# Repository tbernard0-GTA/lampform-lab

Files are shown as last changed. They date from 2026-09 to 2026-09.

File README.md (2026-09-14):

# LampForm Lab v0.9 — Entender, escolher, comparar, imprimir

[Story](https://lampform-lab.oieszc.chatgpt.site/) · [Design](https://lampform-lab.oieszc.chatgpt.site/design/) · [Test](https://lampform-lab.oieszc.chatgpt.site/test/) · [Advanced](https://lampform-lab.oieszc.chatgpt.site/advanced/)

Cinco capítulos apresentam a pesquisa. Design guia uma decisão por tela: peça, pergunta, hipótese, comparação visual e interpretação. Os resultados mostram separadamente melhora, piora e custo de material, sem um score que esconda os trade-offs. Advanced reúne os 48 designs e os dados de engenharia.

As peças e arquivos finais agora se chamam **Peça 1** e **Peça 2**. Os pacotes incluem `peca-1-controle.stl`, `peca-1-largura.stl`, `peca-1-altura.stl`, `peca-1-combinada.stl` e `molde-peca-1.stl`, com equivalentes para Peça 2. Os nomes técnicos internos são preservados para manter a rastreabilidade.

Esta versão muda somente a experiência. Solver, catálogo, métricas e STLs da v0.8 permanecem idênticos, verificados por hash. Os arquivos renomeados são cópias exatas. [Decisões de experiência](docs/V09_EXPERIENCE.md).

`npm run build` recompila a interface; `npm test` verifica o conjunto. As imagens e pacotes já estão incluídos. Para recriar apenas esses materiais, use Python com as dependências do projeto e execute `scripts/render-test-thumbnails.py`, `scripts/build-comparison-visuals.py` e `scripts/package-public-tests.py`, nessa ordem. Nenhum deles executa o solver.

## Referência: v0.8 — Parametric Lattice Design Lab

[A história](https://lampform-lab.oieszc.chatgpt.site) · [Design Lab](https://lampform-lab.oieszc.chatgpt.site/design/) · [STLs e mapas V2](https://lampform-lab.oieszc.chatgpt.site/downloads/LAMPFORM_PARAMETRIC_TEST_V2.zip)

A página inicial conta a pesquisa em sete capítulos. O laboratório separa os controles avançados e oferece 48 configurações calculadas: Honeycomb, Triangle e Diamond, comparação por volume equivalente e um experimento de largura versus altura para as duas peças.

Cada seleção corresponde a uma geometria, solver e STL reais. Os controles ajustam explicitamente a seleção ao catálogo disponível; não existe interpolação de métricas ou execução do solver no navegador. A adaptação local está disponível em Honeycomb. Triangle e Diamond têm estados uniformes e de volume equivalente.

O pacote V2 tem A uniforme, B largura variável, C altura variável e D ambas, por peça. Alturas em passos de 0,1 mm; B/C/D usam aproximadamente +10% de volume da malha. São hipóteses para ensaio, sem comprovação física. A altura variável não melhora todos os resultados.

Regenerar: `npm run analysis:parametric` com o ambiente Python ativado; depois `npm run build` e `npm test`. O script BUILD inclui todas as análises. [Método v0.8](docs/V08_IMPLEMENTATION_NOTES.md) · [Resultados completos](docs/V08_CALCULATED_CATALOG.md).

## Referência preservada: v0.6 — Physical Validation Loop

[Aplicação pública](https://lampform-lab.oieszc.chatgpt.site) · [Story Mode](https://lampform-lab.oieszc.chatgpt.site/story.html?scene=01) · [Método e resultados v0.6](docs/LAMPFORM_V06_PHYSICAL_VALIDATION.md) · [Storyboard](docs/VIDEO_STORYBOARD.md)

Uma bancada para prever, fabricar, medir e comparar uma luminária impressa plana e termoformada. Não existem medições físicas ou calibração do polímero nesta versão.

## Novidades v0.6

Geometry → Deformation → Mechanisms → Design → Compare → Experiment → Calibration → Print. Inspecione λ1, λ2, J, anisotropia e direções por célula. Use Change only e Zoom da alteração para examinar os novos testes. HAB-2 e Sub-Merged têm escolhas independentes e podem ser baixadas juntas num ZIP.

Print oferece A/B/C/D do Sub-Merged, com STL reais, plano de 20 células por peça, template e procedimento. B/C/D investigam mecanismos; não melhoram o P95 no modelo atual. Os originais fornecidos e os reparados têm arquivos separados.

Experiment aceita CSV/JSON e entrada manual. Os dados ficam na memória deste navegador; exporte antes de fechar ou recarregar. Valores ausentes permanecem ausentes. A calibração usa Original e uma amostra Candidate separada da mesma peça.

Story Mode tem 12 cenas. Setas e Space navegam; Esc volta à bancada. Abra `story.html?scene=06` ou `story.html?scene=06&mode=capture` para gravação limpa em 16:9. Capture frame exporta a cena atual; `npm run capture-story` gera as 12 imagens offline em `docs/video_frames/`, com os mesmos dados e composição própria.

O site compilado e os resultados já estão incluídos. `npm start` ou `PLAY-LAMPFORM-LAB.cmd` abre localmente. Depois de instalar as dependências abaixo, a geração completa usa:

```powershell
.\.venv\Scripts\python.exe analysis/build_design_space.py
.\.venv\Scripts\python.exe analysis/build_physical.py
npm run build
npm test
npm run capture-story
```

`BUILD-LAMPFORM-LAB.cmd` inclui as duas análises. Com o ambiente Python ativado, `npm run analysis:physical` regenera a v0.6. Depois de obter medidas reais, exporte um trabalho na aba Calibration e execute `python analysis/calibrate_physical.py calibration_job.json`. Importe o relatório selecionando os mesmos datasets. Ele não substitui silenciosamente as previsões base.

O catálogo v0.6 usa `dist/data/physical/results.json`. A bancada anterior está preservada em [workbench-v05.html](https://lampform-lab.oieszc.chatgpt.site/workbench-v05.html). O método, limites e resultados negativos estão documentados no relatório v0.6.

## Referência preservada: Engineering Workbench v0.5

[Aplicação pública](https://lampform-lab.oieszc.chatgpt.site) · [Relatório de engenharia](docs/LAMPFORM_V05_ENGINEERING_REPORT.md)

Uma bancada visual para investigar uma luminária impressa plana e termoformada. Compare Original e candidatos reais, localize concentração de demanda, veja mudanças geométricas, diferenças e alimentação XY, e baixe o STL exato.

## Uso

Abra o site e selecione HAB-2 ou Sub-Merged, família e intensidade. Os dois viewers compartilham câmera e escala de cores. O mapa plano permite inspecionar células, sobrepor geometrias, mostrar apenas alterações, examinar delta e vetores XY. Danger zones, matriz ordenável e gráficos separam risco de custo de fabricação. Story / About conta o contexto.

Os resultados são calculados offline. O site não executa Python, não recebe uploads e não oferece edição pública. O repositório é público; modificações no repositório principal dependem do proprietário. A visibilidade pública permite leitura e forks conforme as regras do GitHub; não concede acesso de escrita.

## Gerar novamente

Requisitos: Python 3.13+ e Node.js 22+. Dependências científicas fixadas em requirements-analysis.txt.

No Windows: execute BUILD-LAMPFORM-LAB.cmd. Depois use PLAY-LAMPFORM-LAB.cmd para abrir localmente.

```powershell
python -m venv .venv
.\.venv\Scripts\python.exe -m pip install -r requirements-analysis.txt
npm ci
.\.venv\Scripts\python.exe analysis/build_design_space.py
npm run build
npm test
npm start
```

Com o ambiente Python ativado, o comando principal é `python analysis/build_design_space.py`. A pipeline anterior permanece disponível em `python analysis/run_design_sweep.py` e gera o catálogo v0.4 separado.

O modo opcional `--reuse-solutions` reaproveita soluções somente se coordenadas, arestas, larguras, comprimentos, ancoragens, parent IDs, parâmetros do solver e hash do STL coincidirem. O modo padrão recalcula tudo.

## Modelo e gates

Dez designs iniciais: Original e três intensidades de Reserve, Boundary e Hybrid. Se nenhum par passar, até três perturbações adicionais de Reserve são testadas. Cada tentativa fica em generated/sweep/. Sem ML e sem métricas interpoladas.

Risco: 30% P95 + 25% P99 + 25% máximo + 20% fração crítica, normalizados ao Original. Material e área aberta ficam separados. Print gate: P95 menor, menos ligamentos acima de 30%, pico no máximo +5 pontos percentuais, solução convergida e geometria válida. A recomendação exige aprovação das DUAS peças. Nenhum vencedor é inventado se a busca terminar sem aprovação.

## Arquivos

- legacy/: material original preservado, incluindo os quatro STL e os scripts v0.1/v0.2.
- analysis/: geometria, rede estrutural, solver, geração, gates, exportação e relatórios.
- config/manufacturing.yaml: defaults de fabricação (JSON compatível com YAML 1.2).
- generated/baseline_reproduction.json: comparação da reprodução dos scripts originais.
- generated/sweep/: resultados, parâmetros, redes e CSV de todas as tentativas.
- dist/data/results.json: catálogo completo v0.5.
- dist/downloads/: STL e ZIP reais, métricas, parâmetros e instruções.
- web/: fonte do app estático; dist/: versão compilada publicada.

## Limites

É um modelo de demanda geométrica/estrutural relativa, não FEA termomecânico calibrado. Não prevê temperatura, E(T), viscoelasticidade, atrito, anisotropia ou ruptura real. A vista formada é a rede analítica nas etapas calculadas; o STL exato é mostrado plano.

Os STL originais das lâmpadas têm faces duplicadas e não são watertight; são preservados sem reparos. Os candidatos são novos sólidos fechados e mantêm o aro original. Mold e Push nunca são alterados. Os checks de largura cobrem caminhos estruturais e a sonda de abertura cobre células principais; cantos e vãos periféricos devem ser revistos no slicer.

Consulte o relatório para resultados, rejeições, alcance da validação e recomendação física (ou ausência dela).

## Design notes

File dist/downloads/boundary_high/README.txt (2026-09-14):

LampForm Lab v0.5 / Boundary High
Both-part print gate: False
Boundary High: abertura equivalente média 6.65 mm; material projetado -2.4%; geometria plana alterada 69.1%. P95 36.0 → 47.3%; P99 45.3 → 74.0%; pico 64.3 → 87.8%; críticos 45 → 60. Transição com núcleo escalado a 96.0%, conectores de 0.95 mm e amplitude máxima 0.65 mm. Gates: REJECTED.
Boundary High: abertura equivalente média 6.65 mm; material projetado -2.4%; geometria plana alterada 69.1%. P95 55.5 → 108.8%; P99 70.1 → 132.2%; pico 83.9 → 158.9%; críticos 98 → 104. Transição com núcleo escalado a 96.0%, conectores de 0.95 mm e amplitude máxima 0.65 mm. Gates: REJECTED.
Units mm. Flat lattice 1 mm, original rim 4 mm. Inspect layers in your slicer. Relative geometric model, not calibrated polymer strain. Mold and Push unchanged. Original source meshes have duplicated faces and are not watertight.

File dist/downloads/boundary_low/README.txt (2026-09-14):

LampForm Lab v0.5 / Boundary Low
Both-part print gate: False
Boundary Low: abertura equivalente média 6.85 mm; material projetado -0.0%; geometria plana alterada 27.0%. P95 36.0 → 36.1%; P99 45.3 → 55.5%; pico 64.3 → 62.4%; críticos 45 → 55. Transição com núcleo escalado a 99.0%, conectores de 1.20 mm e amplitude máxima 0.15 mm. Gates: REJECTED.
Boundary Low: abertura equivalente média 6.85 mm; material projetado -0.0%; geometria plana alterada 27.0%. P95 55.5 → 112.2%; P99 70.1 → 161.3%; pico 83.9 → 182.3%; críticos 98 → 106. Transição com núcleo escalado a 99.0%, conectores de 1.20 mm e amplitude máxima 0.15 mm. Gates: REJECTED.
Units mm. Flat lattice 1 mm, original rim 4 mm. Inspect layers in your slicer. Relative geometric model, not calibrated polymer strain. Mold and Push unchanged. Original source meshes have duplicated faces and are not watertight.

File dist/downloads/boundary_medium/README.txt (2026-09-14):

LampForm Lab v0.5 / Boundary Medium
Both-part print gate: False
Boundary Medium: abertura equivalente média 6.79 mm; material projetado -0.9%; geometria plana alterada 45.9%. P95 36.0 → 40.0%; P99 45.3 → 58.1%; pico 64.3 → 75.2%; críticos 45 → 43. Transição com núcleo escalado a 98.0%, conectores de 1.05 mm e amplitude máxima 0.35 mm. Gates: REJECTED.
Boundary Medium: abertura equivalente média 6.79 mm; material projetado -0.9%; geometria plana alterada 45.9%. P95 55.5 → 99.5%; P99 70.1 → 131.1%; pico 83.9 → 162.0%; críticos 98 → 110. Transição com núcleo escalado a 98.0%, conectores de 1.05 mm e amplitude máxima 0.35 mm. Gates: REJECTED.
Units mm. Flat lattice 1 mm, original rim 4 mm. Inspect layers in your slicer. Relative geometric model, not calibrated polymer strain. Mold and Push unchanged. Original source meshes have duplicated faces and are not watertight.

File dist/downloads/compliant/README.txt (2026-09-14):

LampForm Lab v0.4 / compliant
Units: mm. Flat pieces; lattice 1 mm, rim 4 mm.
HAB-2 -> Mold; Sub-Merged -> Push. Tools are unchanged.
Open both STL in a slicer and inspect layers before printing.
Relative geometric/structural demand, NOT calibrated polymer strain.
Parameters, convergence and mesh checks are in the accompanying JSON files.
Candidate geometry reloaded and checked closed, single body, with no duplicate or degenerate faces.

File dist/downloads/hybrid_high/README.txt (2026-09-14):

LampForm Lab v0.5 / Hybrid High
Both-part print gate: False
Hybrid High: abertura equivalente média 6.20 mm; material projetado +18.3%; geometria plana alterada 65.3%. P95 36.0 → 44.0%; P99 45.3 → 86.5%; pico 64.3 → 116.1%; críticos 45 → 55. Transição com núcleo escalado a 96.0%, conectores de 0.95 mm e amplitude máxima 0.65 mm. Gates: REJECTED.
Hybrid High: abertura equivalente média 6.32 mm; material projetado +13.3%; geometria plana alterada 65.6%. P95 55.5 → 75.7%; P99 70.1 → 130.9%; pico 83.9 → 179.3%; críticos 98 → 92. Transição com núcleo escalado a 96.0%, conectores de 0.95 mm e amplitude máxima 0.65 mm. Gates: REJECTED.
Units mm. Flat lattice 1 mm, original rim 4 mm. Inspect layers in your slicer. Relative geometric model, not calibrated polymer strain. Mold and Push unchanged. Original source meshes have duplicated faces and are not watertight.

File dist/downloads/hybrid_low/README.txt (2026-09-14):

LampForm Lab v0.5 / Hybrid Low
Both-part print gate: False
Hybrid Low: abertura equivalente média 6.76 mm; material projetado +4.5%; geometria plana alterada 27.0%. P95 36.0 → 37.9%; P99 45.3 → 57.9%; pico 64.3 → 68.4%; críticos 45 → 42. Transição com núcleo escalado a 99.0%, conectores de 1.20 mm e amplitude máxima 0.15 mm. Gates: REJECTED.
Hybrid Low: abertura equivalente média 6.79 mm; material projetado +3.4%; geometria plana alterada 26.7%. P95 55.5 → 114.0%; P99 70.1 → 172.0%; pico 83.9 → 188.3%; críticos 98 → 103. Transição com núcleo escalado a 99.0%, conectores de 1.20 mm e amplitude máxima 0.15 mm. Gates: REJECTED.
Units mm. Flat lattice 1 mm, original rim 4 mm. Inspect layers in your slicer. Relative geometric model, not calibrated polymer strain. Mold and Push unchanged. Original source meshes have duplicated faces and are not watertight.

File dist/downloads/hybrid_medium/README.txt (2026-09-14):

LampForm Lab v0.5 / Hybrid Medium
Both-part print gate: False
Hybrid Medium: abertura equivalente média 6.51 mm; material projetado +12.3%; geometria plana alterada 44.7%. P95 36.0 → 39.8%; P99 45.3 → 71.3%; pico 64.3 → 77.2%; críticos 45 → 40. Transição com núcleo escalado a 98.0%, conectores de 1.05 mm e amplitude máxima 0.35 mm. Gates: REJECTED.
Hybrid Medium: abertura equivalente média 6.59 mm; material projetado +9.0%; geometria plana alterada 44.1%. P95 55.5 → 85.5%; P99 70.1 → 136.2%; pico 83.9 → 187.6%; críticos 98 → 108. Transição com núcleo escalado a 98.0%, conectores de 1.05 mm e amplitude máxima 0.35 mm. Gates: REJECTED.
Units mm. Flat lattice 1 mm, original rim 4 mm. Inspect layers in your slicer. Relative geometric model, not calibrated polymer strain. Mold and Push unchanged. Original source meshes have duplicated faces and are not watertight.

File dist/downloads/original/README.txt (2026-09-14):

LampForm Lab v0.5 / Original
Both-part print gate: False
Original: abertura equivalente média 6.93 mm; material projetado +0.0%; geometria plana alterada 0.0%. P95 36.0 → 36.0%; P99 45.3 → 45.3%; pico 64.3 → 64.3%; críticos 45 → 45. Gates: BASE.
Original: abertura equivalente média 6.93 mm; material projetado +0.0%; geometria plana alterada 0.0%. P95 55.5 → 55.5%; P99 70.1 → 70.1%; pico 83.9 → 83.9%; críticos 98 → 98. Gates: BASE.
Units mm. Flat lattice 1 mm, original rim 4 mm. Inspect layers in your slicer. Relative geometric model, not calibrated polymer strain. Mold and Push unchanged. Original source meshes have duplicated faces and are not watertight.

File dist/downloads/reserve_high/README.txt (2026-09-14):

LampForm Lab v0.5 / Reserve High
Both-part print gate: False
Reserve High: abertura equivalente média 6.47 mm; material projetado +20.7%; geometria plana alterada 24.1%. P95 36.0 → 29.6%; P99 45.3 → 34.9%; pico 64.3 → 37.0%; críticos 45 → 10. Gates: PASS.
Reserve High: abertura equivalente média 6.61 mm; material projetado +14.5%; geometria plana alterada 18.3%. P95 55.5 → 51.4%; P99 70.1 → 97.6%; pico 83.9 → 107.8%; críticos 98 → 88. Gates: TRADE-OFF.
Units mm. Flat lattice 1 mm, original rim 4 mm. Inspect layers in your slicer. Relative geometric model, not calibrated polymer strain. Mold and Push unchanged. Original source meshes have duplicated faces and are not watertight.

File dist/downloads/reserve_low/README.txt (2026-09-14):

LampForm Lab v0.5 / Reserve Low
Both-part print gate: False
Reserve Low: abertura equivalente média 6.83 mm; material projetado +4.5%; geometria plana alterada 7.0%. P95 36.0 → 35.4%; P99 45.3 → 46.7%; pico 64.3 → 69.0%; críticos 45 → 43. Gates: PASS.
Reserve Low: abertura equivalente média 6.86 mm; material projetado +3.2%; geometria plana alterada 5.3%. P95 55.5 → 53.3%; P99 70.1 → 72.8%; pico 83.9 → 88.1%; críticos 98 → 98. Gates: TRADE-OFF.
Units mm. Flat lattice 1 mm, original rim 4 mm. Inspect layers in your slicer. Relative geometric model, not calibrated polymer strain. Mold and Push unchanged. Original source meshes have duplicated faces and are not watertight.

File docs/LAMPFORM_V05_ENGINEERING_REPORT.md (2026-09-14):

# LampForm Lab v0.5 — Engineering report

Generated: 2026-09-14T16:59:59.122447+00:00

## Baseline problem

The supplied v0.1 and v0.2 solvers were reproduced without editing legacy; deviations below 0.02 percentage point are recorded in `generated/baseline_reproduction.json`. This DOE recomputes its own baseline with exactly the candidate solver. It merges nominally coincident corners at 0.03 mm and includes 20 actual rim connectors: 246 parent ligaments per part. Reported demand is the maximum positive segment strain per physical parent, so subdividing a connector does not dilute percentiles. The original STL are copied byte-for-byte; both contain 503 duplicated faces and are not watertight.

## Design space and mechanisms

Ten initial designs: Original and Low/Medium/High Reserve, Boundary and Hybrid. Reserve reduces cell openings by up to 2/6/10%, spatially smoothed over 12 mm. Boundary contracts the core to 99/98/96% and adds actual S connectors, width 1.20/1.05/0.95 mm and maximum amplitude 0.15/0.35/0.65 mm. Hybrid combines these levels. Nominal boundary-band parameters 0.4/0.8/1.6 mm are converted to isotropic scale using a 40 mm reference; actual gap varies along the perimeter. Boundary changes pitch and connectors together: their individual effects are not isolated. If no pair passes, a bounded second pass tests reserve strengths 0.005, 0.01, 0.035, stopping at the first pass or 13 designs total. Every attempted result is stored in `generated/sweep/` and exposed in the explorer.

## Danger zones and risk

LOW <10%; MODERATE 10–<20%; HIGH 20–30%; CRITICAL >30%. These are relative demand classes, not polymer failure limits. Risk Index = 0.30(P95/P95₀) + 0.25(P99/P99₀) + 0.25(max/max₀) + 0.20(critical fraction/critical fraction₀). Material and open area are excluded. If baseline has zero critical ligaments the denominator floor is one edge. Print gate requires lower P95, fewer >30% ligaments, max ≤ baseline +5 percentage points, valid geometry, closed single body, minimum structural path width and aperture probe. A pair is recommended only when BOTH parts pass. Gates are selection heuristics, not a safety certification.

## Results

| Design | Part | P95 | P99 | Max | Critical | Risk | Material Δ | Gate |
|---|---|---:|---:|---:|---:|---:|---:|---|
| Original | hab2 | 35.98% | 45.29% | 64.33% | 45 | 1.000 | +0.0% | BASE |
| Original | submerged | 55.47% | 70.12% | 83.86% | 98 | 1.000 | +0.0% | BASE |
| Reserve Low | hab2 | 35.35% | 46.73% | 69.03% | 43 | 1.012 | +4.5% | PASS |
| Reserve Low | submerged | 53.26% | 72.81% | 88.13% | 98 | 1.010 | +3.2% | TRADE-OFF |
| Reserve Medium | hab2 | 34.32% | 48.83% | 80.79% | 44 | 1.065 | +12.7% | TRADE-OFF |
| Reserve Medium | submerged | 50.92% | 79.41% | 87.02% | 93 | 1.008 | +8.9% | PASS |
| Reserve High | hab2 | 29.61% | 34.93% | 36.98% | 10 | 0.628 | +20.7% | PASS |
| Reserve High | submerged | 51.44% | 97.61% | 107.80% | 88 | 1.127 | +14.5% | TRADE-OFF |
| Boundary Low | hab2 | 36.09% | 55.50% | 62.38% | 55 | 1.094 | -0.0% | REJECTED |
| Boundary Low | submerged | 112.17% | 161.33% | 182.30% | 106 | 1.942 | -0.0% | REJECTED |
| Boundary Medium | hab2 | 39.97% | 58.10% | 75.23% | 43 | 1.137 | -0.9% | REJECTED |
| Boundary Medium | submerged | 99.51% | 131.07% | 161.99% | 110 | 1.713 | -0.9% | REJECTED |
| Boundary High | hab2 | 47.33% | 73.95% | 87.81% | 60 | 1.411 | -2.4% | REJECTED |
| Boundary High | submerged | 108.82% | 132.17% | 158.89% | 104 | 1.746 | -2.4% | REJECTED |
| Hybrid Low | hab2 | 37.85% | 57.93% | 68.41% | 42 | 1.088 | +4.5% | REJECTED |
| Hybrid Low | submerged | 114.04% | 171.98% | 188.27% | 103 | 2.001 | +3.4% | REJECTED |
| Hybrid Medium | hab2 | 39.81% | 71.34% | 77.18% | 40 | 1.203 | +12.3% | REJECTED |
| Hybrid Medium | submerged | 85.49% | 136.22% | 187.57% | 108 | 1.728 | +9.0% | REJECTED |
| Hybrid High | hab2 | 44.00% | 86.47% | 116.06% | 55 | 1.540 | +18.3% | REJECTED |
| Hybrid High | submerged | 75.66% | 130.86% | 179.33% | 92 | 1.598 | +13.3% | REJECTED |
| Reserve Search 1 | hab2 | 32.65% | 37.77% | 63.03% | 34 | 0.877 | +1.3% | PASS |
| Reserve Search 1 | submerged | 54.49% | 69.90% | 84.00% | 100 | 0.998 | +1.0% | TRADE-OFF |
| Reserve Search 2 | hab2 | 35.55% | 46.54% | 66.90% | 43 | 1.004 | +2.4% | PASS |
| Reserve Search 2 | submerged | 53.91% | 70.35% | 85.52% | 98 | 0.997 | +1.7% | TRADE-OFF |
| Reserve Search 3 | hab2 | 29.72% | 32.24% | 35.06% | 10 | 0.606 | +7.6% | PASS |
| Reserve Search 3 | submerged | 50.59% | 71.25% | 84.63% | 97 | 0.978 | +5.3% | PASS |

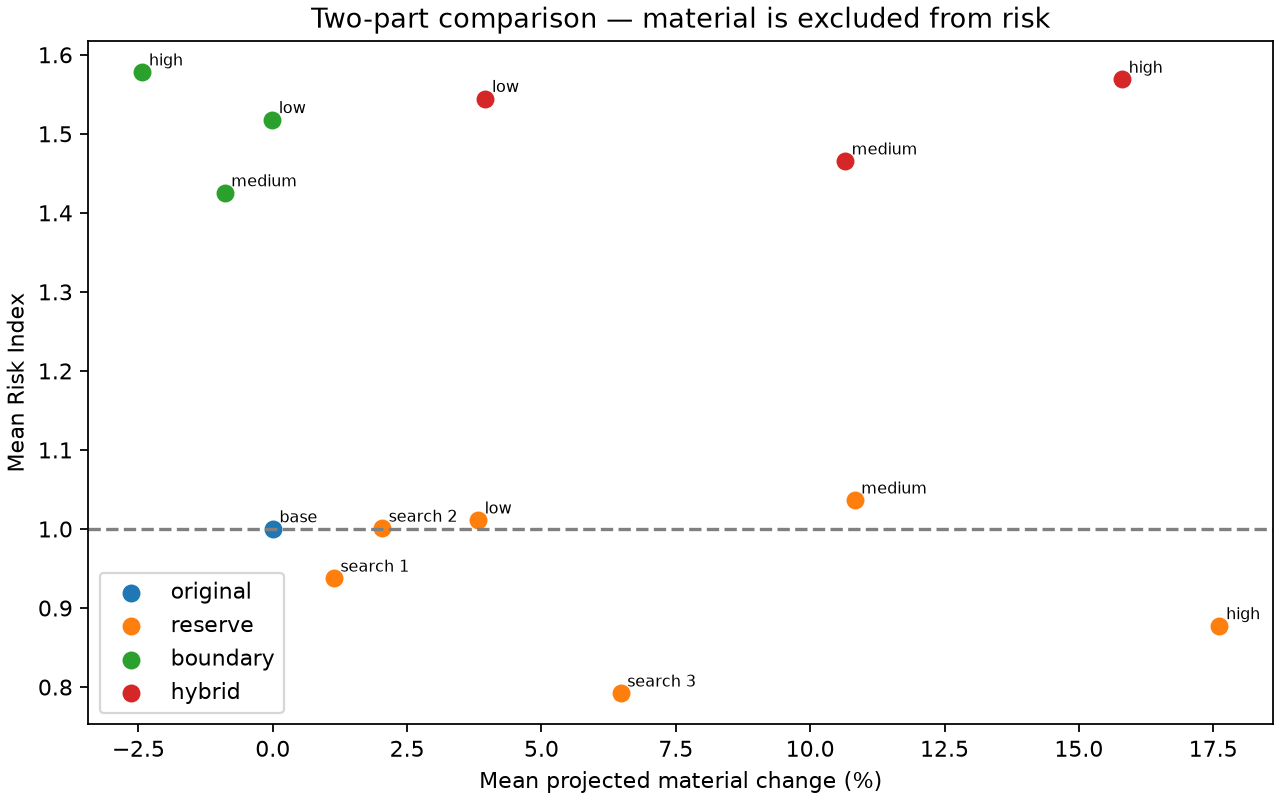
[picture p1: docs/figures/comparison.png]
Risk versus material


## Sensitivity: material, boundary or combination?

- Reserve: two-part Risk Index range 0.878–1.036; 0 pairs passed.
- Boundary: two-part Risk Index range 1.425–1.578; 0 pairs passed.
- Hybrid: two-part Risk Index range 1.465–1.569; 0 pairs passed.

The smallest observed risk in this tested space belongs to reserve. This is a comparison of tested perturbations, not a causal attribution or proof of global optimality. The boundary family alters both pitch and connector shape. A matched-pitch follow-up and physical measurements are needed to isolate rim feed from material amount.

## Rejected candidates

- Reserve Low: submerged: critical_edges
- Reserve Medium: hab2: maximum
- Reserve High: submerged: maximum
- Boundary Low: hab2: p95, hab2: critical_edges, submerged: p95, submerged: critical_edges, submerged: maximum
- Boundary Medium: hab2: p95, hab2: maximum, submerged: p95, submerged: critical_edges, submerged: maximum
- Boundary High: hab2: p95, hab2: critical_edges, hab2: maximum, submerged: p95, submerged: critical_edges, submerged: maximum
- Hybrid Low: hab2: p95, submerged: p95, submerged: critical_edges, submerged: maximum
- Hybrid Medium: hab2: p95, hab2: maximum, hab2: solver_converged, submerged: p95, submerged: critical_edges, submerged: maximum
- Hybrid High: hab2: p95, hab2: critical_edges, hab2: maximum, hab2: solver_converged, submerged: p95, submerged: maximum
- Reserve Search 1: submerged: critical_edges
- Reserve Search 2: submerged: critical_edges

## Geometry changes and map correspondence

Parent IDs preserve lattice topology and the same attachment sites across designs; cell IDs preserve original centers, with scaled positions in boundary families. Delta = candidate parent demand − original parent demand, in percentage points. The maps show exact flat footprints plus the corresponding analytical paths. Equivalent hole size = sqrt(2×hole area/sqrt(3)); this is across-flats only for a regular hexagon. Curved candidates use area-equivalent size. Geometry changed % is symmetric-difference area divided by union area, excluding the retained rim. Hole outlines are re-extracted after all unions/cuts. The formed view shows the analytical network, never a fabricated deformed solid. Its five steps are actual continuation solutions.

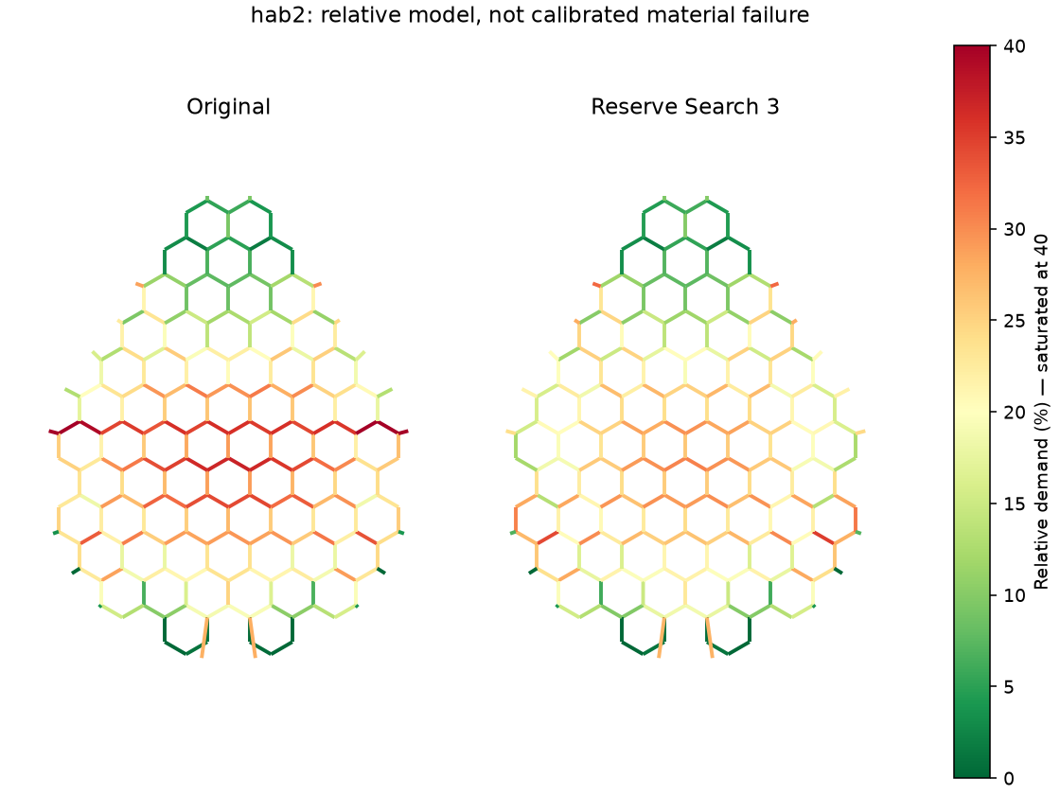
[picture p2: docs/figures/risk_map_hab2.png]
HAB-2 risk

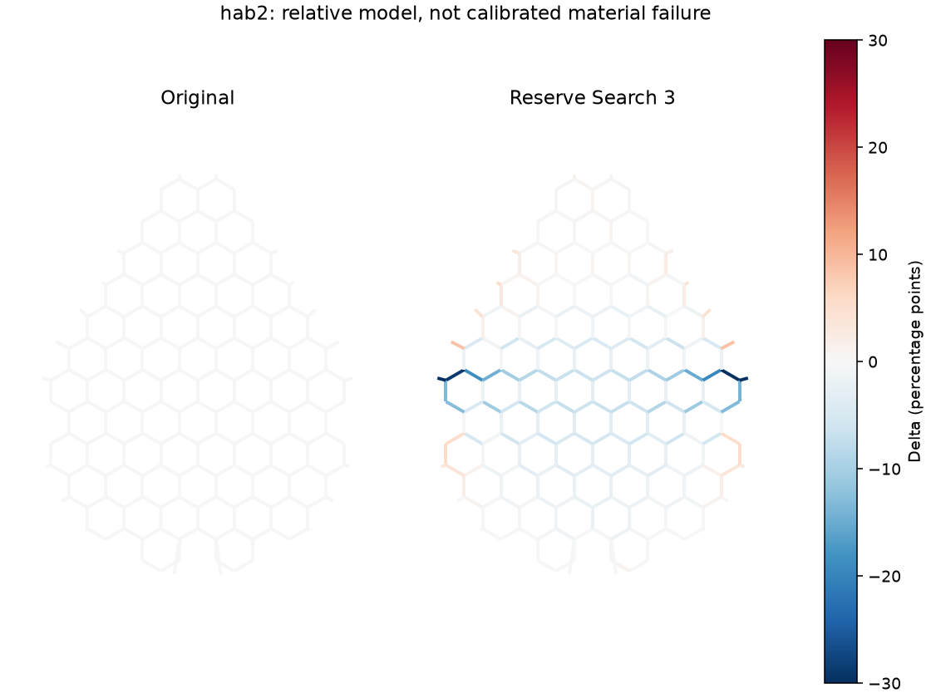
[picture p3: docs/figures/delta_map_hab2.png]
HAB-2 delta

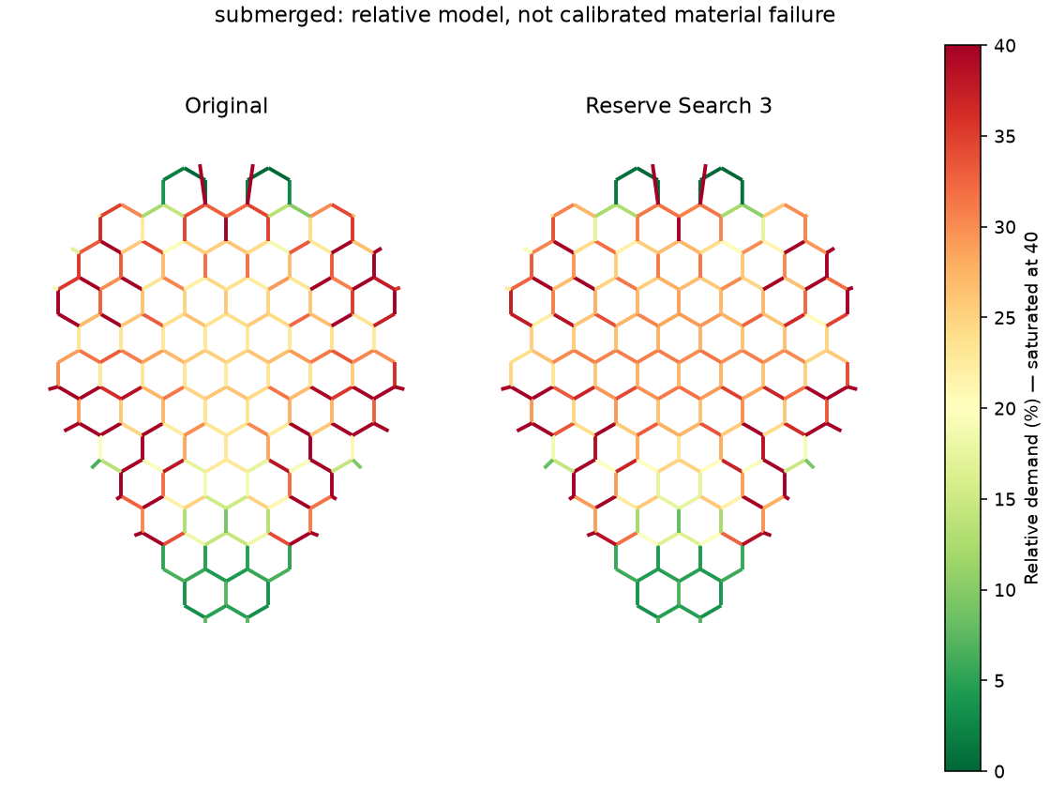
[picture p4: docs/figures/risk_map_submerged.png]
Sub-Merged risk

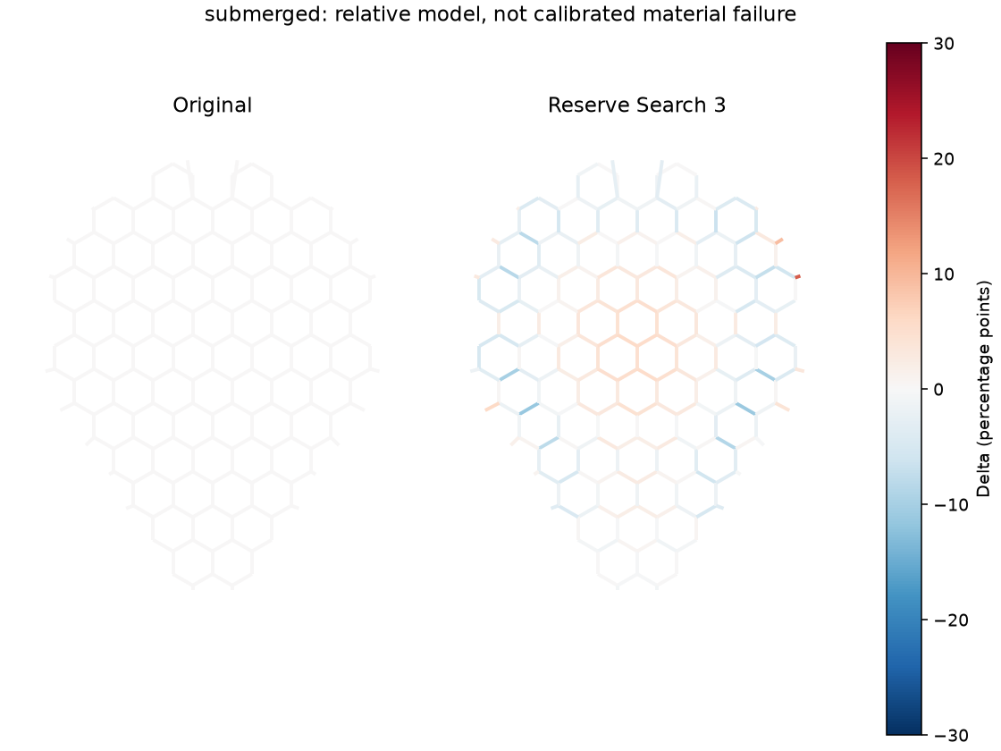
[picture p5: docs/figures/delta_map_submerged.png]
Sub-Merged delta


## Solver limitations

Geometric draping on the STL top envelope, relative axial stiffness, angular penalty, curved material paths and XY feed are modeled. Axial energy scales with width and segment length; angular energy with width cubed and inverse adjacent length. Every design uses the same rim anchor 2.0, interior anchor 0.0005 and angular weight 0.01. Compliance is actual path length/shape, not an arbitrary anchor discount. Solutions are local minima; convergence by tolerance does not prove global optimality. Cost, optimality and continuation stages are retained. Not modeled: calibrated polymer stress, temperature, E(T), viscoelasticity, heating rate, contact friction, layer anisotropy, damage or real failure strain. The solid rim is not a deformable volume mesh; contact is a top-envelope approximation.

## STL validation and manufacturing

Defaults in `config/manufacturing.yaml`: 0.4 mm line, 0.8 mm structural path, 0.4 mm main-cell gap probe, 1 mm lattice and 4 mm retained rim. Candidates are planar extrusions united with the exact original rim via Manifold and reread from the binary STL. Checks: watertight, one body, no degenerate or duplicate faces, consistent winding, finite coordinates, global dimensions within 0.02 mm and no missing rim volume over 0.01 mm³. The 0.8 mm check covers swept structural paths; the gap probe must fit each main cell. It does not certify every tapered corner, peripheral slot or printer profile. The volume proxy uses original rim volume plus planar area outside the rim times thickness, consistently even for the defective original. All manufacturing flags remain separate from structural gates.

## Physical test recommendation

RECOMMENDED FOR PRINT TEST

Passou nos gates das duas peças; menor Risk Index médio entre os aprovados. HAB-2: P95 35.98 → 29.72%; críticos 45 → 10; pico -29.27 p.p. Sub-Merged: P95 55.47 → 50.59%; críticos 98 → 97; pico +0.78 p.p.. Margem pequena em Sub-Merged: redução de apenas um ligamento crítico. Candidato para teste físico; robustez ainda não demonstrada.

RECOMMENDED PHYSICAL TEST
Original vs Reserve Search 3

- Candidate: `HAB-2_TEST_V1_reserve_search_3.stl` and `SubMerged_TEST_V1_reserve_search_3.stl`.
- Reference: `dist/downloads/original/HAB-2.stl` and `dist/downloads/original/Sub-Merged.stl`.

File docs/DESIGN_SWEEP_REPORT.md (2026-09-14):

# LampForm Lab v0.4 — Design sweep

Gerado em 2026-09-14T15:37:15.857506+00:00. Pipeline offline; o site publica dados e arquivos estáticos.

## Baseline reproduzido

Os scripts v0.1 e v0.2 foram executados integralmente em `artifacts/baseline`, sem editar `legacy/`. Todos os quatro baselines convergiram. Diferença máxima <0,02 ponto percentual versus o arquivo fornecido. Dados detalhados: `generated/baseline_reproduction.json`.

A comparação abaixo utiliza um **novo baseline v0.4** calculado pelo mesmo modelo dos candidatos. Não se comparam números antigos da v0.2 com números novos de candidatos. Os cantos coincidentes são unidos com tolerância de 0,03 mm e as ligações ao aro são explícitas e verificadas no material.

## Candidate generation

- **Original:** cópias binárias exatas dos dois STL; paredes medidas em seções transversais do footprint.
- **Gradient:** mesmos centros e pitch nominal; abertura reduzida em até 10%, com suavização espacial de 12 mm do campo baseline.
- **Gradient Boundary:** núcleo do gradiente reduzido a 90% para reservar uma faixa de transição; pontes em S de 0,95 mm ligam os mesmos locais do aro. O pitch do núcleo passa de 8,0 para 7,2 mm. Essa mudança de pitch faz parte do candidato, e seu efeito não é isolado do efeito da borda.
- **Compliant:** somente ligamentos interiores acima do percentil 75 de demanda baseline recebem uma onda S de amplitude 0,65 mm e largura 0,95 mm.

Os candidatos reconstroem a região plana com a altura detectada de 1 mm; pequenos chanfros da malha original são aproximados por extrusão constante. O sólido original do aro, com altura de 4 mm e suas interfaces, é preservado integralmente por união booleana. Mold e Push nunca são modificados.

## What we model

- Rede de caminhos materiais, comprimentos de repouso, larguras relativas e nós sobre a superfície superior real do STL da ferramenta.
- Caminhos curvos explicitamente segmentados; o comprimento adicional existe tanto no solver quanto no STL.
- Mesma ancoragem 2,0 nos endpoints junto ao aro, mesma penalização interior e mesma sequência de carga 25/50/75/100% para todos os designs.

## What we approximate

Energia axial proporcional a `(w/w0) * (L/Lref) * strain²`. A propriedade `axial_stiffness_proxy` é `(w/w0)*(Lref/L)`, um proxy relativo de EA/L. A propriedade `bending_stiffness_proxy` é `(w/w0)^3*(Lref/L)^3`; a penalização angular usa `(w/w0)^3*(Lref/Ldual)` e peso 0,01. A altura é a mesma em todas as peças e está registrada por segmento. O material não tem módulo físico atribuído.

`compliance_factor` registra comprimento do caminho / distância entre endpoints. Não se aplica um desconto adicional de rigidez por esse fator: a subdivisão já representa o caminho, evitando dupla contagem.

Cada ligamento físico contribui **uma vez** aos percentis, com a maior demanda positiva dos seus segmentos. As pontes junto ao aro entram nas métricas; não se ocultam seus picos. Isso impede que uma curva com mais nós dilua o score. A compressão segmentar permanece nos CSV, mas as métricas de demanda usam a parte positiva.

As soluções são mínimos locais numéricos da energia proxy. Término por tolerância não prova ótimo global, e o envelope triangular pode gerar não suavidade. Os arquivos registram custo, critério de parada e optimality para cada etapa.

## What we do not model yet

Temperatura, PETG/PLA constitutivo, viscoelasticidade, anisotropia de impressão, flambagem, dano/ruptura, atrito, espessamento/afinamento real e contato bilateral molde–punção. O aro sólido não é deformado por uma malha volumétrica. Não é FEA termomecânico calibrado. Não há garantia de que pontes terão o mesmo movimento no experimento.

## Comparison

| Design | Peça | P95 % | Máx. % | >20% | Área aberta % | Material mm² | Score |
|---|---|---:|---:|---:|---:|---:|---:|
| Original | hab2 | 35.984 | 64.334 | 61.38% | 66.30 | 1663.97 | 1.0000 |
| Original | submerged | 55.475 | 83.855 | 77.64% | 66.30 | 1663.98 | 1.0000 |
| Gradient | hab2 | 29.613 | 36.979 | 50.00% | 59.31 | 2009.06 | 0.8390 |
| Gradient | submerged | 51.443 | 107.797 | 78.46% | 61.42 | 1905.16 | 1.0913 |
| Gradient + Compliant Boundary | hab2 | 46.805 | 103.375 | 47.56% | 62.35 | 1859.13 | 1.3717 |
| Gradient + Compliant Boundary | submerged | 104.322 | 148.597 | 46.75% | 63.86 | 1784.70 | 1.6494 |
| Compliant | hab2 | 34.237 | 57.833 | 51.63% | 66.14 | 1672.00 | 0.9478 |
| Compliant | submerged | 59.558 | 91.281 | 56.91% | 66.19 | 1669.43 | 1.0739 |

## Score e recomendação

`score = 0.35*(P95/P95₀) + 0.25*(max/max₀) + 0.15*(std/std₀) + 0.15*(material/material₀) + 0.10*(1 + max(0,(open₀-open)/open₀))`.

Menor é melhor. Original = 1. Score combinado = média aritmética das duas peças, com pesos iguais. Material é área projetada sólida; massa é um proxy de volume, sem densidade assumida. Não é uma medida de resistência. Todos os componentes e diferenças percentuais estão nos JSON.

Menor score combinado: **Gradient**. Melhor alternativa nova para confronto experimental: **Gradient**.
Gradient tem o menor score combinado entre as alternativas novas (0.965). A vantagem é apenas prevista pelo modelo e depende de validação física.

## STL validation

| Design | Peça | Watertight | Corpos | Faces degeneradas | Duplicadas | Dimensões mm |
|---|---|---|---:|---:|---:|---|
| original | hab2 | False | 3 | 0 | 503 | 73.294 × 97.073 × 4.000 |
| original | submerged | False | 3 | 0 | 503 | 73.294 × 97.073 × 4.000 |
| gradient | hab2 | True | 1 | 0 | 0 | 73.294 × 97.073 × 4.000 |
| gradient | submerged | True | 1 | 0 | 0 | 73.294 × 97.073 × 4.000 |
| gradient_boundary | hab2 | True | 1 | 0 | 0 | 73.294 × 97.073 × 4.000 |
| gradient_boundary | submerged | True | 1 | 0 | 0 | 73.294 × 97.073 × 4.000 |
| compliant | hab2 | True | 1 | 0 | 0 | 73.294 × 97.073 × 4.000 |
| compliant | submerged | True | 1 | 0 | 0 | 73.294 × 97.073 × 4.000 |

Os originais fornecidos contêm 503 faces duplicadas por peça e não passam no fechamento de malha. São preservados como solicitado e identificados na interface. Os seis STL candidatos devem ser fechados, de corpo único, sem duplicadas/degeneradas e reabrir com dimensões dentro de 0,02 mm do original. Os sólidos novos são extrusões de polígonos válidos unidas com Manifold; o relatório não apresenta watertight isoladamente como prova de ausência de auto-interseção.

A largura mínima é verificada nos caminhos estruturais e não equivale a uma análise de todo canto/chanfro. Geometria imprimível não garante bom comportamento térmico nem sucesso com qualquer perfil de impressora.

## Physical validation plan

1. Abrir os dois STL do pacote no slicer, confirmar dimensões e apoio plano, e revisar as camadas.
2. Imprimir Original e a alternativa escolhida com material, orientação e configurações iguais.
3. Usar o mesmo procedimento térmico e a mesma ferramenta correspondente a cada metade.
4. Marcar referências; fotografar e medir deslocamentos, aberturas, afilamento e ruptura.
5. Comparar contra as tendências previstas e calibrar os pesos antes de interpretar valores como deformação física.

## Referências de implementação

- [SciPy least_squares](https://docs.scipy.org/doc/scipy/reference/generated/scipy.optimize.least_squares.html)
- [Trimesh: extrusão de polígonos](https://trimesh.org/trimesh.creation.html)
- [Manifold: operações booleanas em sólidos](https://github.com/elalish/manifold)

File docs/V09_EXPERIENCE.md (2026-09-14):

# v0.9 — experience only

Visual thesis: a quiet scientific exhibit, with sage physical geometry filling the canvas and one clear decision at a time.

Content plan: five story chapters; Design chooses a part, a question and a hypothesis before revealing comparison and interpretation; Test offers the four controlled samples; Advanced holds all existing engineering data.

Interaction thesis: crossfade between decisions, a synchronized before/after reveal of real solids, and thumbnail hover/focus that makes the chosen experiment tangible. Reduced-motion users receive immediate state changes.

The v0.8 solver, computed catalogue, metrics and STL bytes are frozen. This release changes presentation and packages the same files. A selection group is one primary control: four hypotheses answer one question. Navigation/back links do not count as additional experiment controls. Each Explore screen has no more than three primary control groups.

Main navigation: Story / Design / Test / Advanced. Historical versions remain reachable inside Advanced. Original in the test flow means the generated A_uniform control, with this distinction explained near comparison and downloads. It must never silently claim to be the supplied source STL.

Metric interpretation: lower P95, maximum demand and count of ligaments >30% are better within the current model. Differences ≤0.1 percentage point in demand are labelled similar; counts compare exactly. A mix of better/worse is MIXED RESULT; at least one better and none worse is PROMISING CANDIDATE; otherwise NO CLEAR BENEFIT. Original receives CONTROL SAMPLE. Material cost is shown separately, never silently folded into a score. These labels are comparative geometric evidence, not physical validation.

Equal-volume topology mode uses Honeycomb equal-volume as its reference, not A_uniform. The existing approximately +38% feasible common budget is preserved. Test pairs use the matching baseline. Fine-tuning only enables exact existing combinations; no nearest-value snapping or new calculations.

## Naming and checks

Public labels, folders and filenames use Peça 1 / Peça 2 and Molde da Peça 1 / Molde da Peça 2. Internal IDs remain hab2 / submerged to preserve exact computational provenance. Original source files and historical URLs remain intact. New public aliases and test packages contain byte-identical STL payloads. Mold files are supplied reference tools, renamed without redesign or manufacturing validation.

The comparison ZIP contains reference and candidate STL, the corresponding mold, actual-solid comparison PNG, parameters, metrics and instructions. The four-sample ZIP uses descriptive names first; A/B/C/D are secondary experiment codes.

Equal-volume Difference displays a presentation-only Boolean subtraction of the two existing solids (candidate and equal-volume Honeycomb); it does not reuse the older A_uniform difference or change either STL. All 48 thumbnails are rendered from the actual computed mesh, without invented geometry.

Automated verification includes the real Peça 2 mixed result (P95 49.69→49.26, maximum 75.26→74.28, critical ligaments 94→100), exact fine-tune availability, reference selection, export packaging, friendly filename hashes and frozen v0.8 data. This release has no new physics or physical measurements.

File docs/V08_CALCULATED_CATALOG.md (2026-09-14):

# v0.8 calculated catalogue

Relative geometric model; no physical validation.

| Part | Design | P95 % | Max % | Critical >30% | Lattice volume mm³ | Material Δ % | Height mm | Converged |
|---|---|---:|---:|---:|---:|---:|---|---|
| hab2 | A · Uniform | 35.43 | 64.53 | 42 | 1010.29 | +0.00 | 1.0–1.0 | True |
| hab2 | Uniform · 0.8 × 0.8 mm | 37.19 | 63.58 | 69 | 655.59 | -35.11 | 0.8–0.8 | True |
| hab2 | Uniform · 0.8 × 1 mm | 36.63 | 64.33 | 62 | 819.49 | -18.89 | 1.0–1.0 | True |
| hab2 | Uniform · 0.8 × 1.2 mm | 36.56 | 66.76 | 56 | 983.39 | -2.66 | 1.2–1.2 | True |
| hab2 | Uniform · 1 × 0.8 mm | 36.66 | 64.42 | 61 | 808.23 | -20.00 | 0.8–0.8 | True |
| hab2 | Uniform · 1 × 1.2 mm | 34.88 | 66.13 | 40 | 1212.35 | +20.00 | 1.2–1.2 | True |
| hab2 | Uniform · 1.2 × 0.8 mm | 36.66 | 66.24 | 56 | 956.55 | -5.32 | 0.8–0.8 | True |
| hab2 | Uniform · 1.2 × 1 mm | 36.23 | 66.70 | 52 | 1195.69 | +18.35 | 1.0–1.0 | True |
| hab2 | Uniform · 1.2 × 1.2 mm | 34.95 | 65.70 | 40 | 1434.83 | +42.02 | 1.2–1.2 | True |
| hab2 | B · Width adaptive | 34.95 | 65.02 | 44 | 1111.31 | +10.00 | 1.0–1.0 | True |
| hab2 | C · Height adaptive | 36.40 | 63.61 | 55 | 1111.19 | +9.99 | 1.0–1.2 | True |
| hab2 | D · Width + height | 36.26 | 67.62 | 56 | 1111.30 | +10.00 | 1.0–1.1 | True |
| hab2 | Width response · 50% | 34.95 | 65.02 | 44 | 1111.31 | +10.00 | 1.0–1.0 | True |
| hab2 | Height response · 50% | 36.40 | 63.61 | 55 | 1111.19 | +9.99 | 1.0–1.2 | True |
| hab2 | Width + height · budget 20% | 35.82 | 70.96 | 62 | 1212.33 | +20.00 | 1.0–1.2 | True |
| hab2 | Comply · reduced section | 37.73 | 68.31 | 78 | 767.44 | -24.04 | 0.8–1.0 | True |
| hab2 | Mechanism-aware | 37.07 | 80.23 | 65 | 958.55 | -5.12 | 0.9–1.4 | True |
| hab2 | Honeycomb · pitch 10 | 39.34 | 41.45 | 47 | 821.50 | -18.69 | 1.0–1.0 | True |
| hab2 | Triangle · Uniform | 44.14 | 55.66 | 89 | 1679.66 | +66.26 | 1.0–1.0 | True |
| hab2 | Diamond · Uniform | 42.35 | 51.55 | 70 | 1041.15 | +3.05 | 1.0–1.0 | True |
| hab2 | Honeycomb · Equal volume | 34.94 | 66.23 | 40 | 1396.41 | +38.22 | 1.0–1.0 | True |
| hab2 | Triangle · Equal volume | 46.18 | 54.03 | 98 | 1396.43 | +38.22 | 1.0–1.0 | True |
| hab2 | Diamond · Equal volume | 38.50 | 48.62 | 58 | 1396.42 | +38.22 | 1.0–1.0 | True |
| hab2 | Diamond · rotated 30° | 45.38 | 52.54 | 55 | 1013.22 | +0.29 | 1.0–1.0 | True |
| submerged | A · Uniform | 49.69 | 75.26 | 94 | 1010.25 | +0.00 | 1.0–1.0 | True |
| submerged | Uniform · 0.8 × 0.8 mm | 52.65 | 76.50 | 99 | 655.56 | -35.11 | 0.8–0.8 | True |
| submerged | Uniform · 0.8 × 1 mm | 50.93 | 77.90 | 100 | 819.45 | -18.89 | 1.0–1.0 | True |
| submerged | Uniform · 0.8 × 1.2 mm | 55.27 | 83.46 | 97 | 983.35 | -2.66 | 1.2–1.2 | True |
| submerged | Uniform · 1 × 0.8 mm | 42.71 | 61.35 | 116 | 808.20 | -20.00 | 0.8–0.8 | True |
| submerged | Uniform · 1 × 1.2 mm | 57.19 | 84.18 | 96 | 1212.30 | +20.00 | 1.2–1.2 | True |
| submerged | Uniform · 1.2 × 0.8 mm | 54.41 | 82.97 | 99 | 956.52 | -5.32 | 0.8–0.8 | True |
| submerged | Uniform · 1.2 × 1 mm | 53.64 | 82.72 | 97 | 1195.66 | +18.35 | 1.0–1.0 | True |
| submerged | Uniform · 1.2 × 1.2 mm | 53.11 | 84.90 | 83 | 1434.79 | +42.02 | 1.2–1.2 | True |
| submerged | B · Width adaptive | 49.68 | 78.25 | 84 | 1111.27 | +10.00 | 1.0–1.0 | True |
| submerged | C · Height adaptive | 56.75 | 87.60 | 93 | 1110.74 | +9.95 | 1.0–1.2 | True |
| submerged | D · Width + height | 49.26 | 74.28 | 100 | 1110.78 | +9.95 | 1.0–1.1 | True |
| submerged | Width response · 50% | 49.68 | 78.25 | 84 | 1111.27 | +10.00 | 1.0–1.0 | True |
| submerged | Height response · 50% | 56.75 | 87.60 | 93 | 1110.74 | +9.95 | 1.0–1.2 | True |
| submerged | Width + height · budget 20% | 49.96 | 77.05 | 89 | 1212.25 | +19.99 | 1.0–1.2 | True |
| submerged | Comply · reduced section | 68.99 | 106.79 | 98 | 828.18 | -18.02 | 0.8–1.0 | True |
| submerged | Mechanism-aware | 77.35 | 115.68 | 104 | 991.40 | -1.87 | 0.9–1.2 | True |
| submerged | Honeycomb · pitch 10 | 43.50 | 52.57 | 99 | 821.50 | -18.68 | 1.0–1.0 | True |
| submerged | Triangle · Uniform | 51.63 | 83.65 | 144 | 1679.66 | +66.26 | 1.0–1.0 | True |
| submerged | Diamond · Uniform | 57.97 | 71.92 | 74 | 1041.15 | +3.06 | 1.0–1.0 | True |
| submerged | Honeycomb · Equal volume | 55.48 | 81.97 | 98 | 1396.41 | +38.22 | 1.0–1.0 | True |
| submerged | Triangle · Equal volume | 51.64 | 70.12 | 142 | 1396.43 | +38.23 | 1.0–1.0 | True |
| submerged | Diamond · Equal volume | 60.55 | 71.58 | 68 | 1396.42 | +38.22 | 1.0–1.0 | True |
| submerged | Diamond · rotated 30° | 47.74 | 52.53 | 82 | 1013.22 | +0.29 | 1.0–1.0 | True |

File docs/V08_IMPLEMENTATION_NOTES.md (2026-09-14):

# v0.8 implementation notes

Visual thesis: an off-white engineering documentary with a large, real lattice as the visual anchor; sage material, restrained typography, and color used only for quantitative fields.

Content plan: seven short chapters (Part, Problem, Digital model, Deformation, Redesign, Prediction, Physical test); the advanced controls live in /design, and earlier workbenches remain accessible.

Interaction thesis: a deliberate chapter crossfade, camera transitions between top/iso/side, and a slow sequence from uniform geometry to width/height adaptation using actual computed designs. Visual height exaggeration never changes downloads.

Computation strategy: bounded exact offline catalogue, all controls snap visibly to real generated/solved configurations. Variable height is quantized to 0.1 mm; beam section proxies distinguish area, in-plane inertia and out-of-plane inertia. Only XY node translations are independent solver degrees of freedom. No calibrated thermal or polymer failure predictions.

## Catalogue and interpretation

48 configurations, 24 per part. Uniform width/height combinations, three topologies, pitch and orientation examples, Reinforce/Comply and mechanism heuristics, and an equal-volume trio. Local adaptation is currently catalogued for Honeycomb only. Unsupported values snap visibly to an existing configuration within the selected topology. Controls always display the selected configuration. The static application retrieves its exact result; it does not run or interpolate the Python solver.

A_uniform is a generated reference with width and total lattice height 1 mm. Its original honeycomb graph and supplied rim are retained; it is not the supplied source STL. Source geometry remains available in the v0.6 workbench. The prior original deformation field guides the smoothed redesign, which is then solved again using the v0.8 section-aware surrogate. Cell IDs correspond only within the same topology and pitch.

Width and height affect axial section A=w·h and in-plane inertia I=h·w³/12. Out-of-plane inertia w·h³/12 is recorded, but independent out-of-plane bending is not solved. Angular penalties are relative geometric regularizers, not a calibrated beam finite-element model. Formed views show the solved network on the target surface; flat views and STL downloads show the actual manufactured solid.

The material budget excludes the unchanged rim. B/C/D target a +10% cap relative to A; height quantization can leave unused material. Width response 50% and 100% can reach the same capped solution. Equal-volume topology comparison uses the smallest common feasible range under width limits, about +38.22% vs A, rather than claiming a +10% solution exists for all topologies. All three have height 1 mm. Use actual volumes in the catalogue to compare.

Height means total lattice height. Parent edges have 0.1 mm quantization, neighboring height/width changes ≤0.2 mm, and 12 mm Gaussian smoothing. Junction end sections take the maximum neighboring height. The original rim is retained; its fillets are not quantized. Manifold union is simplified within 0.001 mm to remove serialization slivers, then the exported STL is reloaded and checked for watertightness, one body, finite coordinates, duplicate/degenerate faces, bounds and missing rim volume <0.01 mm.

## Verification

54 automated checks pass: 39 Node and 15 Python tests, including reload/hash checks for all 48 STLs, solver section properties, DOE factor isolation, neighboring feature bounds, fair-volume matching, exact catalogue selection and preserved v0.6 behavior.

Eight A/B/C/D STLs were sliced locally with installed CuraEngine 5.9.0 at 0.1 mm layer height: all returned success, 40 layers and no warnings/errors. This is a command-line check, not proof that every small feature survives the print process. The user chose to inspect the STL layers in Cura themselves. No printer job was submitted. Local G-code and printer settings are excluded from publication.

Permanent limitation: variable height changes structural stiffness and thermal response. Local heating differences, polymer behavior, contact and failure thresholds remain uncalibrated. No physical measurements were generated. The calculated P95 values should be compared within this v0.8 model, not directly with older solver versions.

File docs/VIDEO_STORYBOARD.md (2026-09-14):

# Video storyboard — LampForm Lab v0.6

1920 × 1080; 12 cenas. ←/→ e Space navegam; Esc volta à bancada. Detalhes de cada cena têm controles próprios. URL: story.html?scene=06; captura limpa: story.html?scene=06&mode=capture.

## 01 — The object

Visual: Flat STL → Mold ghost

Main point: The lamp starts as a flat FDM lattice and is thermoformed into a doubly curved shell.

Suggested narration: Apresentar a peça original real. A falha na termoformação é o problema relatado pelo autor; ainda não há registro experimental no app.

Duration hint: 15 s; camera: isometric.

## 02 — The problem

Visual: Flat → Formed → High demand

Main point: A flat lattice cannot conform to this surface without stretching, rotating or feeding material.

Suggested narration: Mostrar a incompatibilidade geométrica; não chamar as cores de tensão PETG.

Duration hint: 15 s; camera: isometric.

## 03 — The mold

Visual: Mold / Push → Dimensions

Main point: The real mold geometry becomes the target surface, instead of an assumed hemisphere.

Suggested narration: As duas ferramentas vêm dos STL originais. Posições de apresentação não simulam contato entre ferramentas.

Duration hint: 15 s; camera: isometric.

## 04 — Digital reconstruction

Visual: Real STL → Detected cells → Nodes → Ligaments

Main point: Real STL → detected cells → nodes → ligaments.

Suggested narration: Explicar a correspondência entre 65 aberturas detectadas e a rede equivalente.

Duration hint: 15 s; camera: top.

## 05 — Forming

Visual: 0% → 25% → 50% → 75% → 100%

Main point: The solver searches for how the network can move in-plane while conforming to the mold.

Suggested narration: Cada etapa vem de uma solução real de continuação do solver.

Duration hint: 15 s; camera: isometric.

## 06 — Where does it want to deform?

Visual: λ1 → λ2 → Principal direction

Main point: The important question is not only how much deformation is required, but in which direction.

Suggested narration: Distinguir magnitudes e direções. Direções quase isotrópicas não são identificáveis.

Duration hint: 22 s; camera: top.

## 07 — The mechanisms

Visual: MATERIAL RESERVE → DIRECTIONAL COMPLIANCE → BOUNDARY FEED → AREA EXPANSION

Main point: Different regions may require different mechanisms.

Suggested narration: As categorias são hipóteses heurísticas, não mecanismos fisicamente provados.

Duration hint: 15 s; camera: top.

## 08 — Original design

Visual: Flat honeycomb → Risk map

Main point: Locate critical regions before changing the geometry.

Suggested narration: P95, máximo e contagem crítica vêm do mesmo modelo de referência.

Duration hint: 15 s; camera: top.

## 09 — Generative response

Visual: Overlay → Hole / ligament → Directional reserve → Boundary only

Main point: Test geometric reserve aligned with the estimated geometric mechanism.

Suggested narration: Mostrar exatamente onde há reserva e conectores curvos. Um conceito ondulado bidirecional não prova auxeticidade.

Duration hint: 15 s; camera: top.

## 10 — Does it improve?

Visual: Original | Candidate → Delta map

Main point: Improvement can move the problem: keep the same camera and color scale.

Suggested narration: Comparar melhora e piora. Sub-Merged permanece o problema mais difícil.

Duration hint: 15 s; camera: top.

## 11 — Simulation is not validation

Visual: Prediction → Print → Thermoform → Measure

Main point: A better simulation score does not prove a better physical part.

Suggested narration: Explicar por que obter um STL não encerra o trabalho.

Duration hint: 15 s; camera: isometric.

## 12 — Physical validation loop

Visual: A Original → B Reserve → C Boundary → D Hybrid → Predicted vs measured

Main point: MODEL → TEST → CALIBRATE → PREDICT

Suggested narration: Imprimir A/B/C/D, medir, calibrar no Original e validar em Candidate separado. Não existem medidas físicas ainda.

Duration hint: 15 s; camera: top.

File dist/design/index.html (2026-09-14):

LAMPFORM LABv0.9

← VoltarDESIGN · EXPLORE

01 · A PEÇA

# Qual peça você quer explorar?

Escolha a referência para o seu experimento.

02 · A PERGUNTA

# O que você quer investigar?

01

### Distribuir material

Largura versus altura. O que muda na resposta?

↗02

### Mudar a célula

Honeycomb, Triangle e Diamond com o mesmo volume.

↗03

### Imprimir um teste

Quatro amostras, uma pergunta para a peça real.

↗

03 · A HIPÓTESE

# O que você quer testar?

Cada opção abre um design já calculado.

03 · A CÉLULA

# Mesma quantidade de material.

A referência é Honeycomb com volume equivalente. Escolha a célula que quer comparar.

Este experimento usa o volume comum viável já calculado, cerca de +38% frente ao controle uniforme. A altura é 1 mm nas três topologias.

04 · O QUE MUDOU

GeometryDeformationDifference

ORIGINALNOVO DESIGN

Original Novo design

O modelo prevê melhora? →

05 · VALE IMPRIMIR?

↓ melhor · ↑ pior · ≈ similar (até 0,1 ponto percentual). Regiões críticas são ligamentos acima de 30%; não são falhas físicas observadas.

Fine tune design · opções calculadas

TEST STATUS

Download test pair · Original + Candidate ↓Download current STL ↓

O ZIP inclui os dois STLs, comparação visual, parâmetros, métricas e instruções. A altura também altera o aquecimento; a resposta térmica local ainda não foi calibrada.

AJUSTE OPCIONAL

# Escolha um valor calculado.

Apenas combinações existentes ficam habilitadas. Nenhum cálculo novo é executado.

Pesquisa aberta · previsões geométricas, sem validação física.Código e método ↗ (https://github.com/tbernard0-GTA/lampform-lab)

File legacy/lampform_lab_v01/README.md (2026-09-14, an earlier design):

# LampForm Lab v0.1 — drape geométrico da luminária

Este laboratório usa os quatro STL fornecidos para estimar a incompatibilidade geométrica entre as duas peças planas e as superfícies reais das ferramentas de conformação.

## Associação geométrica detectada

- `obj_1_HAB-2.stl` → `obj_2_Mold.stl`
- `obj_3_Sub-merged body.stl` → `obj_4_Push.stl`

Os contornos assimétricos das peças e das ferramentas coincidem por orientação: HAB-2 tem a região larga no mesmo extremo do Mold; Sub-merged body coincide com Push.

## O que o v0.1 calcula

1. Faz uma seção da peça plana em `z = 0,5 mm`.
2. Detecta automaticamente as 65 aberturas hexagonais.
3. Usa os centros das células para construir uma rede de vizinhança de passo ~8 mm.
4. Extrai a superfície superior real do STL da ferramenta como `z = f(x,y)`.
5. Calcula dois casos:
   - **projeção direta**: X/Y ficam travados e a rede é levada diretamente para `z=f(x,y)`;
   - **drape relaxado**: os centros podem migrar em X/Y sobre a ferramenta, enquanto a borda recebe ancoragem mais forte e a rede tenta preservar seus comprimentos originais.
6. Gera um primeiro candidato de preenchimento com mais reserva de material nas zonas de maior demanda.

## Interpretação correta dos números

`effective stretch` NÃO é ainda deformação verdadeira do PETG/PLA e NÃO é tensão de von Mises. É a variação de comprimento das arestas de uma rede geométrica equivalente de centros de células. O objetivo desta etapa é localizar incompatibilidade geométrica e estimar quanto fluxo de material no plano reduz o problema.

O caso de projeção direta funciona como um limite muito rígido e superestima fortemente a deformação nos ombros da ferramenta. O caso relaxado é mais representativo da capacidade da malha vazada de deslocar, girar e alimentar material durante a termoformagem, mas ainda não inclui rigidez real dos ligamentos, temperatura, atrito ou contato macho-fêmea.

## Resultados v0.1

### HAB-2 → Mold

- 65 células e 164 relações de vizinhança.
- Projeção direta: média de demanda efetiva ~18,0%; P95 ~60,9%; pico ~152,7%.
- Drape relaxado: média ~7,5%; P95 ~15,4%; pico ~21,2%.
- Fluxo lateral necessário: média ~1,19 mm; máximo ~2,47 mm.
- Primeiro candidato: lado dos hexágonos de aproximadamente 3,36 a 3,97 mm, contra 4,00 mm atuais, criando maior ligamento nas regiões críticas.

### Sub-merged body → Push

- 65 células e 164 relações de vizinhança.
- Projeção direta: média ~19,8%; P95 ~68,3%; pico ~165,5%.
- Drape relaxado: média ~8,0%; P95 ~15,1%; pico ~23,7%.
- Fluxo lateral necessário: média ~1,47 mm; máximo ~3,32 mm.
- Primeiro candidato: lado dos hexágonos de aproximadamente 3,34 a 4,00 mm.

A redução enorme entre projeção direta e drape relaxado mostra que alguns milímetros de movimento no plano têm impacto maior do que simplesmente engrossar toda a peça.

## Candidato v0.1

O candidato v0.1 é deliberadamente conservador e heurístico. Para cada célula, parte da demanda residual do drape relaxado é convertida em **reserva de material**: a abertura hexagonal diminui localmente e o ligamento aumenta. Ele NÃO deve ser tratado como geometria ótima final; serve como primeira peça experimental baseada no campo calculado.

Parâmetros principais estão no dicionário `CONFIG` do script:

- lado atual do hexágono: 4,0 mm;
- pitch: 8,0 mm;
- fator de compensação: 0,65;
- limite de lambda de projeto: 1,22;
- lado mínimo permitido: 2,8 mm.

## Arquivos de resultado

Para cada metade são gerados:

- `*_3d_drape.html`: visualização 3D interativa da ferramenta, projeção direta e drape relaxado;
- `*_relaxed_demand.png`: mapa 2D da demanda geométrica residual;
- `*_candidate_hex_size.png`: tamanho de célula sugerido pelo candidato v0.1;
- `*_original_vs_candidate.svg`: comparação vetorial do desenho plano atual com o candidato;
- `*_cells.csv`: métricas de cada uma das 65 células.

`summary.json` contém as métricas consolidadas.

## Executar

```bash
python lampform_lab_v01.py
```

Dependências utilizadas: `numpy`, `pandas`, `scipy`, `shapely`, `trimesh`, `matplotlib` e `plotly`.

## Próximo gate recomendado — v0.2

Substituir a rede de centros por uma **rede estrutural dos ligamentos reais**. A geometria pode ser reconstruída a partir da tesselação de Voronoi dos centros dos 65 vazios, gerando os eixos das paredes do honeycomb. Cada ligamento passa a ter comprimento, largura, altura e rigidez próprios.

O solver v0.2 deve incluir:

- grandes deslocamentos;
- energia axial e de flexão dos ligamentos;
- nós com rotação/compliance;
- contato com a superfície da ferramenta;
- rigidez da borda de 4 mm;
- variação espacial de largura do ligamento;
- comparação automática entre malha atual e candidatos.

Depois disso, a calibração física deve incorporar material, temperatura, tempo de aquecimento, direção das linhas de impressão e atrito. Só então faz sentido chamar o resultado de FEA termo-mecânico quantitativo.

---

# v0.2 — rede estrutural dos ligamentos

O script `lampform_ligament_v02.py` reconstrói uma rede de **173 nós e 234 ligamentos** a partir da geometria real das 65 células. Em vez de usar apenas os centros dos vazios, ele aproxima os eixos médios das paredes do honeycomb e resolve grandes deslocamentos sobre a superfície real do molde.

É um **beam-network surrogate**, ainda não um FEA constitutivo. O comprimento de cada ligamento é tratado como grau de liberdade estrutural e os nós recebem uma pequena penalização angular. A periferia pode ser mais ou menos ancorada para representar a rigidez do aro e a capacidade de alimentar material durante a conformação.

## Resultado principal da v0.2

Com uma borda relativamente rígida (`boundary_anchor = 2.0`):

- HAB-2 → Mold: demanda axial efetiva média ~20,3%, P95 ~32,8%, máximo ~53,2%.
- Sub-merged → Push: média ~20,8%, P95 ~34,6%, máximo ~51,7%.

Esses números são superiores aos da rede de centros da v0.1 porque agora a métrica é aplicada aos próprios eixos dos ligamentos, que atravessam regiões de gradiente geométrico elevado.

## Descoberta mais importante: sensibilidade ao aro

A varredura de `boundary_anchor` mostra que a capacidade de a periferia alimentar material é um dos parâmetros dominantes do problema.

Para Sub-merged → Push, por exemplo:

- ancoragem 5,0: máximo ~130%;
- 2,0: máximo ~51,7%;
- 0,5: máximo ~43,6%;
- 0,2: P95 ~18,4%;
- 0,05: P95 ~6,2% e máximo ~6,9%.

Isso NÃO significa que `0,05` seja um valor físico calibrado. Significa que, dentro deste modelo, liberar o fluxo da borda pode reduzir a demanda mais do que alterar apenas a flexibilidade angular dos nós.

A sensibilidade à penalização de flexão dos nós foi comparativamente pequena. Isso indica que **"fazer um hexágono mais articulado" sem resolver a restrição da periferia provavelmente não será suficiente**.

## Hipótese de projeto que emerge

A próxima geometria deve testar conjuntamente:

1. **reserva de material local**: reduzir a abertura dos hexágonos nas regiões críticas;
2. **zona de transição compliant entre lattice e aro**: slots, necks, ondas ou segmentos que permitam alguns milímetros de feed durante a termoformagem;
3. **aro final rígido somente depois da formação**, ou um aro com região sacrificial a ser cortada após o processo;
4. comparação contra a peça atual usando as mesmas métricas.

A v0.2 gera, para cada metade:

- `*_ligament_3d.html`: visualizador 3D da rede de ligamentos sobre a ferramenta;
- `*_ligaments.csv`: resultado por ligamento;
- `*_boundary_sensitivity.csv`: sweep da rigidez da periferia;
- `*_boundary_sensitivity.png`: gráfico da influência do aro;
- `summary_v02.json`: consolidação das métricas.

O passo seguinte é transformar a sensibilidade do aro em uma **geometria fabricável**, gerar um candidato STL/SVG e rodar novamente o solver para comparar baseline x candidato.

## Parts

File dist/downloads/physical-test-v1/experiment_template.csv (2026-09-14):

experiment_id | sample_id | date | part | design | material | filament_brand | filament_batch | nozzle_mm | line_width_mm | layer_height_mm | print_temperature_c | bed_temperature_c | print_orientation | heating_device | heating_power | heating_distance_mm | heating_time_s | surface_temperature_c | forming_time_s | hold_time_s | cooling_time_s | cell_id | L1_before_mm | L1_after_mm | L2_before_mm | L2_after_mm | failure | failure_type | notes
 |  |  | submerged | test_a |  |  |  |  |  |  |  |  |  |  |  |  |  |  |  |  |  | S001
 |  |  | submerged | test_a |  |  |  |  |  |  |  |  |  |  |  |  |  |  |  |  |  | S004
 |  |  | submerged | test_a |  |  |  |  |  |  |  |  |  |  |  |  |  |  |  |  |  | S007
 |  |  | submerged | test_a |  |  |  |  |  |  |  |  |  |  |  |  |  |  |  |  |  | S003
 |  |  | submerged | test_a |  |  |  |  |  |  |  |  |  |  |  |  |  |  |  |  |  | S002
 |  |  | submerged | test_a |  |  |  |  |  |  |  |  |  |  |  |  |  |  |  |  |  | S008
 |  |  | submerged | test_a |  |  |  |  |  |  |  |  |  |  |  |  |  |  |  |  |  | S014
 |  |  | submerged | test_a |  |  |  |  |  |  |  |  |  |  |  |  |  |  |  |  |  | S005
 |  |  | submerged | test_a |  |  |  |  |  |  |  |  |  |  |  |  |  |  |  |  |  | S006
 |  |  | submerged | test_a |  |  |  |  |  |  |  |  |  |  |  |  |  |  |  |  |  | S011
 |  |  | submerged | test_a |  |  |  |  |  |  |  |  |  |  |  |  |  |  |  |  |  | S017
 |  |  | submerged | test_a |  |  |  |  |  |  |  |  |  |  |  |  |  |  |  |  |  | S009
 |  |  | submerged | test_a |  |  |  |  |  |  |  |  |  |  |  |  |  |  |  |  |  | S010
 |  |  | submerged | test_a |  |  |  |  |  |  |  |  |  |  |  |  |  |  |  |  |  | S012
 |  |  | submerged | test_a |  |  |  |  |  |  |  |  |  |  |  |  |  |  |  |  |  | S024
 |  |  | submerged | test_a |  |  |  |  |  |  |  |  |  |  |  |  |  |  |  |  |  | S013
 |  |  | submerged | test_a |  |  |  |  |  |  |  |  |  |  |  |  |  |  |  |  |  | S015
 |  |  | submerged | test_a |  |  |  |  |  |  |  |  |  |  |  |  |  |  |  |  |  | S016
 |  |  | submerged | test_a |  |  |  |  |  |  |  |  |  |  |  |  |  |  |  |  |  | S031
 |  |  | submerged | test_a |  |  |  |  |  |  |  |  |  |  |  |  |  |  |  |  |  | S018
 |  |  | submerged | test_b |  |  |  |  |  |  |  |  |  |  |  |  |  |  |  |  |  | S001
 |  |  | submerged | test_b |  |  |  |  |  |  |  |  |  |  |  |  |  |  |  |  |  | S004
 |  |  | submerged | test_b |  |  |  |  |  |  |  |  |  |  |  |  |  |  |  |  |  | S007
 |  |  | submerged | test_b |  |  |  |  |  |  |  |  |  |  |  |  |  |  |  |  |  | S003
 |  |  | submerged | test_b |  |  |  |  |  |  |  |  |  |  |  |  |  |  |  |  |  | S002
 |  |  | submerged | test_b |  |  |  |  |  |  |  |  |  |  |  |  |  |  |  |  |  | S008
 |  |  | submerged | test_b |  |  |  |  |  |  |  |  |  |  |  |  |  |  |  |  |  | S014
 |  |  | submerged | test_b |  |  |  |  |  |  |  |  |  |  |  |  |  |  |  |  |  | S005
 |  |  | submerged | test_b |  |  |  |  |  |  |  |  |  |  |  |  |  |  |  |  |  | S006
 |  |  | submerged | test_b |  |  |  |  |  |  |  |  |  |  |  |  |  |  |  |  |  | S011
 |  |  | submerged | test_b |  |  |  |  |  |  |  |  |  |  |  |  |  |  |  |  |  | S017
 |  |  | submerged | test_b |  |  |  |  |  |  |  |  |  |  |  |  |  |  |  |  |  | S009
 |  |  | submerged | test_b |  |  |  |  |  |  |  |  |  |  |  |  |  |  |  |  |  | S010
 |  |  | submerged | test_b |  |  |  |  |  |  |  |  |  |  |  |  |  |  |  |  |  | S012
 |  |  | submerged | test_b |  |  |  |  |  |  |  |  |  |  |  |  |  |  |  |  |  | S024
 |  |  | submerged | test_b |  |  |  |  |  |  |  |  |  |  |  |  |  |  |  |  |  | S013
 |  |  | submerged | test_b |  |  |  |  |  |  |  |  |  |  |  |  |  |  |  |  |  | S015
 |  |  | submerged | test_b |  |  |  |  |  |  |  |  |  |  |  |  |  |  |  |  |  | S016
 |  |  | submerged | test_b |  |  |  |  |  |  |  |  |  |  |  |  |  |  |  |  |  | S031
 |  |  | submerged | test_b |  |  |  |  |  |  |  |  |  |  |  |  |  |  |  |  |  | S018
 |  |  | submerged | test_c |  |  |  |  |  |  |  |  |  |  |  |  |  |  |  |  |  | S001
 |  |  | submerged | test_c |  |  |  |  |  |  |  |  |  |  |  |  |  |  |  |  |  | S004
 |  |  | submerged | test_c |  |  |  |  |  |  |  |  |  |  |  |  |  |  |  |  |  | S007
 |  |  | submerged | test_c |  |  |  |  |  |  |  |  |  |  |  |  |  |  |  |  |  | S003
 |  |  | submerged | test_c |  |  |  |  |  |  |  |  |  |  |  |  |  |  |  |  |  | S002
 |  |  | submerged | test_c |  |  |  |  |  |  |  |  |  |  |  |  |  |  |  |  |  | S008
 |  |  | submerged | test_c |  |  |  |  |  |  |  |  |  |  |  |  |  |  |  |  |  | S014
 |  |  | submerged | test_c |  |  |  |  |  |  |  |  |  |  |  |  |  |  |  |  |  | S005
 |  |  | submerged | test_c |  |  |  |  |  |  |  |  |  |  |  |  |  |  |  |  |  | S006
 |  |  | submerged | test_c |  |  |  |  |  |  |  |  |  |  |  |  |  |  |  |  |  | S011
 |  |  | submerged | test_c |  |  |  |  |  |  |  |  |  |  |  |  |  |  |  |  |  | S017
 |  |  | submerged | test_c |  |  |  |  |  |  |  |  |  |  |  |  |  |  |  |  |  | S009
 |  |  | submerged | test_c |  |  |  |  |  |  |  |  |  |  |  |  |  |  |  |  |  | S010
 |  |  | submerged | test_c |  |  |  |  |  |  |  |  |  |  |  |  |  |  |  |  |  | S012
 |  |  | submerged | test_c |  |  |  |  |  |  |  |  |  |  |  |  |  |  |  |  |  | S024
 |  |  | submerged | test_c |  |  |  |  |  |  |  |  |  |  |  |  |  |  |  |  |  | S013
 |  |  | submerged | test_c |  |  |  |  |  |  |  |  |  |  |  |  |  |  |  |  |  | S015
 |  |  | submerged | test_c |  |  |  |  |  |  |  |  |  |  |  |  |  |  |  |  |  | S016
 |  |  | submerged | test_c |  |  |  |  |  |  |  |  |  |  |  |  |  |  |  |  |  | S031
 |  |  | submerged | test_c |  |  |  |  |  |  |  |  |  |  |  |  |  |  |  |  |  | S018
 |  |  | submerged | test_d |  |  |  |  |  |  |  |  |  |  |  |  |  |  |  |  |  | S001
 |  |  | submerged | test_d |  |  |  |  |  |  |  |  |  |  |  |  |  |  |  |  |  | S004
 |  |  | submerged | test_d |  |  |  |  |  |  |  |  |  |  |  |  |  |  |  |  |  | S007
 |  |  | submerged | test_d |  |  |  |  |  |  |  |  |  |  |  |  |  |  |  |  |  | S003
 |  |  | submerged | test_d |  |  |  |  |  |  |  |  |  |  |  |  |  |  |  |  |  | S002
 |  |  | submerged | test_d |  |  |  |  |  |  |  |  |  |  |  |  |  |  |  |  |  | S008
 |  |  | submerged | test_d |  |  |  |  |  |  |  |  |  |  |  |  |  |  |  |  |  | S014
 |  |  | submerged | test_d |  |  |  |  |  |  |  |  |  |  |  |  |  |  |  |  |  | S005
 |  |  | submerged | test_d |  |  |  |  |  |  |  |  |  |  |  |  |  |  |  |  |  | S006
 |  |  | submerged | test_d |  |  |  |  |  |  |  |  |  |  |  |  |  |  |  |  |  | S011
 |  |  | submerged | test_d |  |  |  |  |  |  |  |  |  |  |  |  |  |  |  |  |  | S017
 |  |  | submerged | test_d |  |  |  |  |  |  |  |  |  |  |  |  |  |  |  |  |  | S009
 |  |  | submerged | test_d |  |  |  |  |  |  |  |  |  |  |  |  |  |  |  |  |  | S010
 |  |  | submerged | test_d |  |  |  |  |  |  |  |  |  |  |  |  |  |  |  |  |  | S012
 |  |  | submerged | test_d |  |  |  |  |  |  |  |  |  |  |  |  |  |  |  |  |  | S024
 |  |  | submerged | test_d |  |  |  |  |  |  |  |  |  |  |  |  |  |  |  |  |  | S013
 |  |  | submerged | test_d |  |  |  |  |  |  |  |  |  |  |  |  |  |  |  |  |  | S015
 |  |  | submerged | test_d |  |  |  |  |  |  |  |  |  |  |  |  |  |  |  |  |  | S016
 |  |  | submerged | test_d |  |  |  |  |  |  |  |  |  |  |  |  |  |  |  |  |  | S031
 |  |  | submerged | test_d |  |  |  |  |  |  |  |  |  |  |  |  |  |  |  |  |  | S018

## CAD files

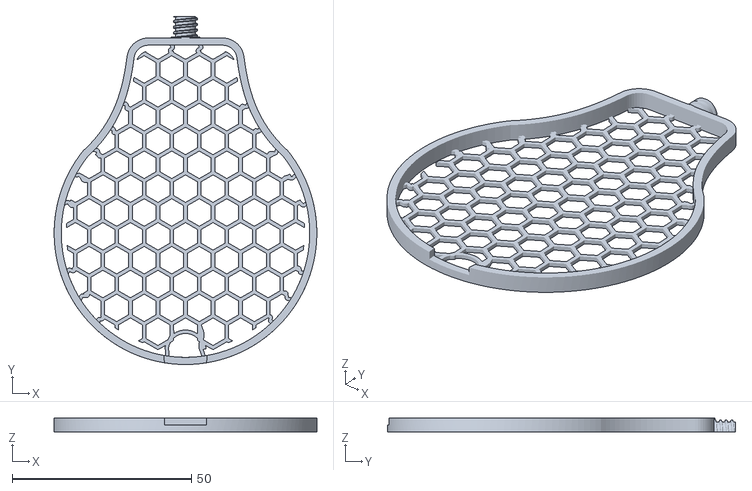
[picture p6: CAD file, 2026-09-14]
dist/downloads/boundary_high/HAB-2.stl
73.3 x 97.1 x 4.00

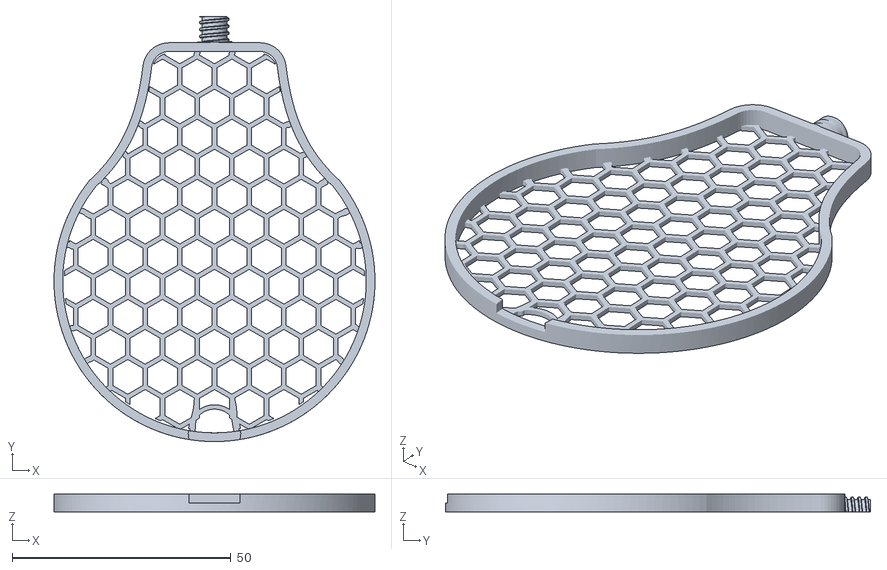
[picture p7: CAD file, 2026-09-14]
dist/downloads/boundary_low/HAB-2.stl
73.3 x 97.1 x 4.00

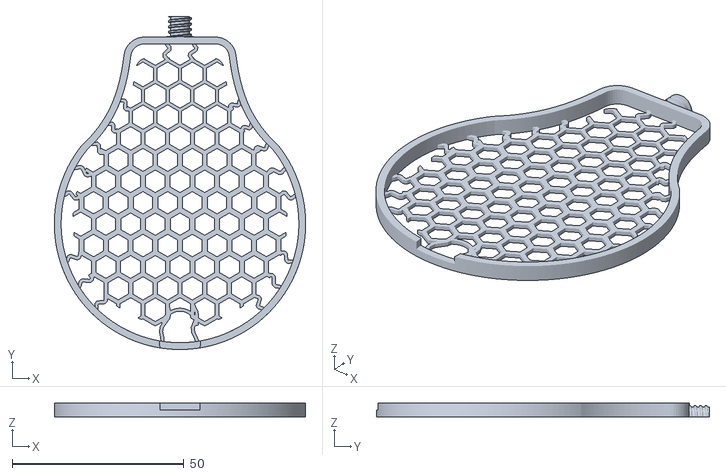
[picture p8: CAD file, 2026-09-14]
dist/downloads/gradient-boundary/HAB-2.stl
73.3 x 97.1 x 4.00

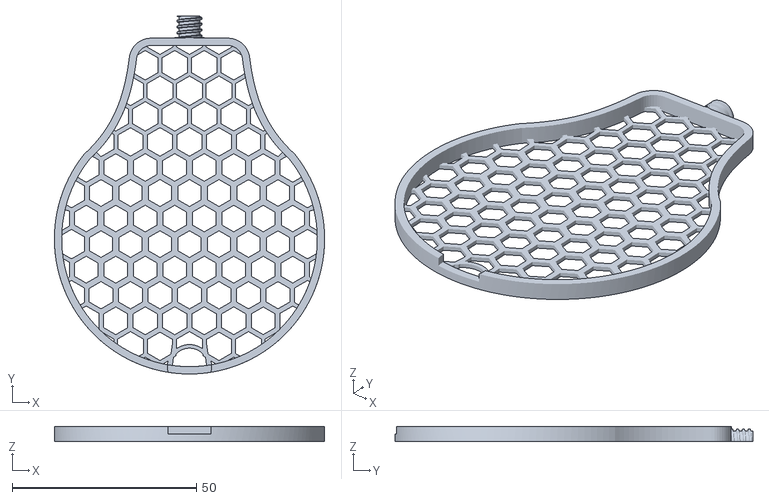
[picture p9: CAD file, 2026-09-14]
dist/downloads/gradient/HAB-2.stl
73.3 x 97.1 x 4.00

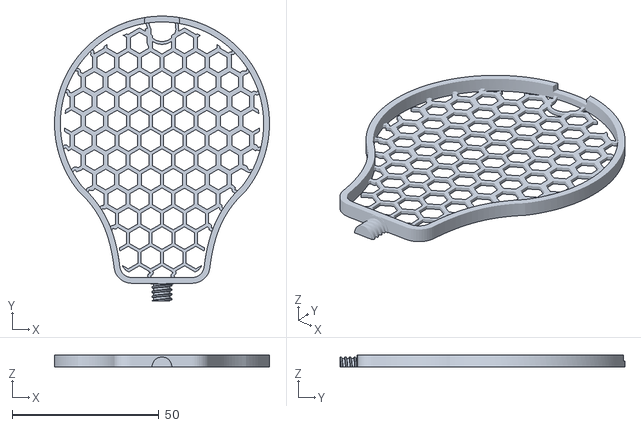
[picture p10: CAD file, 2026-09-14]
dist/downloads/hybrid_high/Sub-Merged.stl
73.3 x 97.1 x 4.00

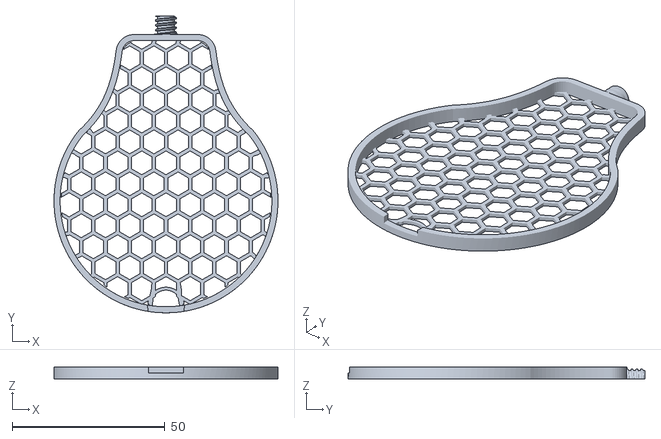
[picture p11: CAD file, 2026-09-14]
dist/downloads/hybrid_low/HAB-2.stl
73.3 x 97.1 x 4.00

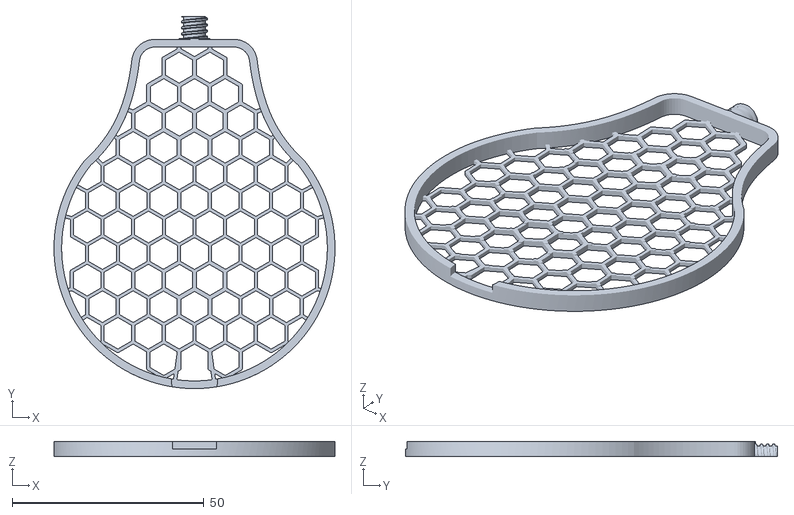
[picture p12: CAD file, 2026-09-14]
dist/downloads/peca-1/peca-1-mechanism.stl
73.3 x 97.1 x 4.00

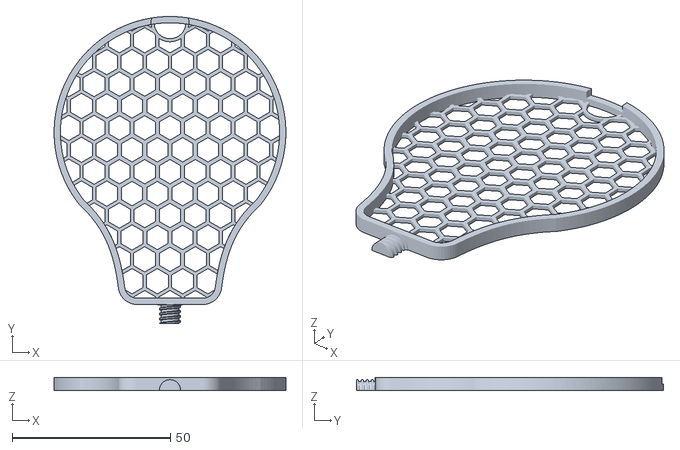
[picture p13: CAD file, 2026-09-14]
dist/downloads/physical-test-v1/TEST_B_RESERVE.stl
73.3 x 97.1 x 4.00

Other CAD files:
dist/downloads/boundary_medium/Sub-Merged.stl
dist/downloads/compliant/HAB-2.stl
dist/downloads/hybrid_medium/HAB-2.stl
dist/downloads/peca-2/peca-2-both-budget20.stl
dist/downloads/physical/area/submerged/Sub-Merged.stl
dist/downloads/physical/directional/submerged/Sub-Merged.stl
dist/downloads/physical/test_a/hab2/HAB-2.stl
dist/downloads/physical/test_a/submerged/Sub-Merged.stl
dist/downloads/physical/test_c/submerged/Sub-Merged.stl
dist/downloads/HAB-2_TEST_V1_reserve_search_3.stl
dist/downloads/SubMerged_TEST_V1_reserve_search_3.stl
dist/downloads/boundary_high/Sub-Merged.stl
dist/downloads/boundary_low/Sub-Merged.stl
dist/downloads/boundary_medium/HAB-2.stl
dist/downloads/compliant/Sub-Merged.stl
dist/downloads/gradient-boundary/Sub-Merged.stl
dist/downloads/gradient/Sub-Merged.stl
dist/downloads/hybrid_high/HAB-2.stl
dist/downloads/hybrid_low/Sub-Merged.stl
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

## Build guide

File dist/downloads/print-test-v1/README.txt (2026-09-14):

PRINT TEST V1
Design: Reserve Search 3
Why selected: Passou nos gates das duas peças; menor Risk Index médio entre os aprovados. HAB-2: P95 35.98 → 29.72%; críticos 45 → 10; pico -29.27 p.p. Sub-Merged: P95 55.47 → 50.59%; críticos 98 → 97; pico +0.78 p.p.. Margem pequena em Sub-Merged: redução de apenas um ligamento crítico. Candidato para teste físico; robustez ainda não demonstrada.
Reserve Search 3: abertura equivalente média 6.77 mm; material projetado +7.6%; geometria plana alterada 10.9%. P95 36.0 → 29.7%; P99 45.3 → 32.2%; pico 64.3 → 35.1%; críticos 45 → 10. Gates: PASS.
Reserve Search 3: abertura equivalente média 6.82 mm; material projetado +5.3%; geometria plana alterada 8.1%. P95 55.5 → 50.6%; P99 70.1 → 71.2%; pico 83.9 → 84.6%; críticos 98 → 97. Gates: PASS.
Flat pieces, mm; lattice 1, rim 4. Review slicer layers. Print Original and candidate with the same material, orientation and thermal procedure; photograph and measure openings, feed and rupture. Relative model, no calibrated material failure limits. Original source STL have defects retained unchanged.

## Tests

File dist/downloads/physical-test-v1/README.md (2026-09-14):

# LAMPFORM PHYSICAL TEST V1

Sub-Merged A/B/C/D: experimento para aprender mecanismos. HAB-2: original reparado vs Reserve escolhido independentemente.

ORIGINAL_* são os arquivos fornecidos, com defeitos preservados. TEST_A e *_repaired_for_test reconstroem a extrusão de 1 mm da pegada nominal e fazem união Manifold com o aro original de 4 mm. Não há alteração intencional do padrão; tolerância de exportação 0,0001 mm. C preserva núcleo e furos; modifica somente dois conectores longos. Os conectores curtos permanecem iguais.

Mapas sem sufixo referem-se ao Sub-Merged. Azul indica direção d1 de referência; use d2 perpendicular. IDs estáveis H001–H065 e S001–S065. Campo de deformação de seis nós por célula; direção pouco determinada quando λ1/λ2 ≤1,02. CSV contém células planejadas, SEM medições inventadas.

NO PHYSICAL VALIDATION DATA YET. Inspecione camadas antes de imprimir. Consulte test_procedure.md.

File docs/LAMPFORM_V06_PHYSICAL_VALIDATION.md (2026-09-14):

# LampForm Lab v0.6 — Physical Validation Loop

## Problema e escopo

A falha durante termoformação é o problema relatado pelo autor. Esta versão prepara um experimento que pode refutar o modelo: prever regiões de maior deformação, fabricar alterações controladas, medir e comparar. Não existem medições físicas nesta entrega. Não se afirma que uma nova topologia resolveu a falha.

A v0.5 é preservada no commit `6f7215aafdc75ae070fb3aa1d3ddded3cdbdac7f`, no catálogo anterior e em `workbench-v05.html`. HAB-2 e Sub-Merged têm escolhas independentes. Atualmente ambas recebem Reserve Search 3 pelo menor índice de risco entre os candidatos que passam nos gates individuais; isso decorre dos resultados, não de uma obrigação do configurador.

## Geometria e solver

Os quatro STL fornecidos e os scripts históricos permanecem em `legacy/`. O solver usa o envelope da superfície real da ferramenta, deslocamentos XY, demanda axial relativa, rigidez relativa pela largura, penalidade angular e restrição periférica. As cinco etapas exibidas são o estado plano e quatro soluções de continuação. As cores de demanda indicam o resultado final em todas as etapas.

Não são resolvidos tensão calibrada do polímero, campo térmico, E(T), viscoelasticidade, creep, contato com atrito, anisotropia entre camadas, deformação real de ruptura ou dano. O sólido real é mostrado no estado plano; Formed mostra a rede equivalente.

## Campo local: F, λ1, λ2 e direções

Cada uma das 65 células usa os mesmos seis nós de referência em todos os designs. IDs H001–H065 e S001–S065 acompanham geometria, solver e medição. Nós adicionados dentro de caminhos ondulados não alteram essa correspondência.

1. Centralizar as posições planas X (n × 2) e formadas Y (n × 3).
2. Ajustar o plano tangente por PCA/SVD das posições Y; a normal é o vetor de menor variância.
3. Construir uma base tangente ortonormal T (2 × 3) e projetar Z = Y Tᵀ.
4. Resolver por mínimos quadrados X Fᵀ ≈ Z.
5. Decompor F = U diag(λ1, λ2) Vᵀ, com λ1 ≥ λ2. As linhas de Vᵀ são as direções materiais em XY; Tᵀ U dá as direções formadas em 3D.

J = λ1 λ2 aproxima a expansão de área; λ1/λ2 descreve anisotropia geométrica. São medidas de um ajuste celular, não propriedades constitutivas. A implementação segue a convenção de [SVD do NumPy](https://numpy.org/doc/stable/reference/generated/numpy.linalg.svd.html).

Guardamos F, base tangente, normal, RMS do ajuste, RMS fora do plano e determinante com sinal. Um resíduo relativo >20% ou det(F) ≤0 gera aviso. No Original, o maior RMS afim é aproximadamente 1,765 mm no HAB-2 e 1,215 mm no Sub-Merged: algumas células não admitem interpretação afim precisa. J positivo por SVD não deve ocultar inversões; por isso o determinante também é guardado.

As setas mostram ±d1 e comprimento proporcional a |λ1−1|. Quando λ1/λ2 ≤1,02, a direção é pouco determinada e a seta é omitida na bancada. Nos mapas impressos, a linha azul ainda fornece uma orientação de referência convencional; não implica uma direção física resolvida.

## Classificação de mecanismo

É uma heurística de projeto. Os limiares ficam em `analysis/local_deformation.py` e no pacote:

| Categoria | Regra inicial |
|---|---|
| Directional compliance | λ1/λ2 ≥1,15 |
| Area expansion | λ2 >1,04 e J >1,20 |
| Boundary feed | célula periférica, XY >2 mm e sensibilidade periférica absoluta >1 p.p. |
| Material reserve | demanda de ligamento >30% e XY <2 mm |
| Mixed | várias regras ou demanda sem mecanismo isolado |
| Low demand | nenhuma regra, λ1 <1,10 e demanda <10% |

A sensibilidade de borda é uma solução adicional real do Original com boundary_anchor reduzido de 2 para 1. Só Original/A recebe essa informação. Nos demais candidatos, ausência de sensibilidade é declarada; não se inventa a categoria Boundary feed. Clicar numa célula mostra valores, classificação e motivo.

## Matriz causal e reparo

ORIGINAL_* preserva os defeitos topológicos fornecidos. Para comparação física, A e *_original_repaired_for_test reconstroem a extrusão de 1 mm da pegada nominal e fazem união Manifold com o aro original de 4 mm. O padrão nominal permanece; a tolerância de exportação é 0,0001 mm. Use A reparado como controle para evitar comparar um sólido íntegro com uma malha defeituosa.

| Teste Sub-Merged | Núcleo | Transição para o aro |
|---|---|---|
| A | Original | Original |
| B | Reserva: aberturas internas com escala 0,965 | Original |
| C | Original | Dois conectores longos em S |
| D | Igual a B | Igual a C |

A máscara protegida inclui células e caminhos do núcleo. C mantém pitch, posições dos 162 nós do núcleo, geometria das aberturas e material do núcleo: diferença de área protegida = 0. Os 20 caminhos de contato são iguais entre A/B e entre C/D. Apenas dois conectores de aproximadamente 7,7 mm dispõem de região livre suficiente para a alteração C: amplitude 0,25 mm, largura 1 mm. Os outros 18 permanecem iguais. C testa uma intervenção periférica limitada, não uma borda inteiramente flexível.

B acrescenta aproximadamente 105,780768 mm² na máscara do núcleo. D acrescenta 105,780761 mm²: diferença numérica inferior a 0,00001 mm². O teste automático usa tolerância de 0,0001 mm². O aro permanece preservado.

Dois conceitos adicionais geram STL reais: ligamentos em S alinhados com d1, e ligamentos ondulados em mais de uma orientação onde J é elevado. Ambos usam amplitude 0,4 mm, largura 1 mm e caminhos não adjacentes selecionados. O segundo é um conceito cinemático bidirecional, não uma estrutura auxética comprovada.

## Resultados atuais: hipótese, não vencedor

Demanda de ligamento em %, no Sub-Merged. Todos convergiram; sete STL novos (incluindo A/HAB-2) passaram nos checks geométricos de exportação, com um corpo fechado.

| Design | P95 | P99 | Máximo | Ligamentos >30% |
|---|---:|---:|---:|---:|
| A / Original | 55,475 | 70,124 | 83,855 | 98 |
| B / Reserve only | 60,095 | 83,338 | 95,592 | 92 |
| C / Boundary only | 67,209 | 88,050 | 196,854 | 97 |
| D / Hybrid | 73,716 | 97,880 | 169,938 | 101 |
| Directional S | 69,501 | 88,069 | 107,106 | 101 |
| Bidirectional undulating | 65,315 | 84,055 | 101,118 | 105 |

B/C/D não passam como melhorias. C e D concentram demanda muito alta em regiões do modelo. Esses resultados permanecem visíveis: é preciso testar a hipótese, em vez de escolher pelo aspecto visual. Os checks de STL não garantem imprimibilidade de cada detalhe nem bom comportamento durante aquecimento. Inspeção de camadas continua necessária.

## Medição e comparação

O plano seleciona 20 células por peça, distribuídas entre faixas de demanda, borda e interior. Grupos sem células não são preenchidos artificialmente. O template A/B/C/D tem 80 linhas planejadas, sem qualquer medida ou condição térmica inventada.

Antes de formar, definir dois segmentos materiais alinhados com d1/d2 e marcar seus extremos. Medir os mesmos pontos depois, sem reordenar L1/L2 pelo maior comprimento observado. λ1_medido = L1_depois/L1_antes; λ2_medido = L2_depois/L2_antes; J_medido é o produto. Essas razões ao longo de eixos materiais são proxies das extensões principais; cisalhamento, rotação dos eixos e curvatura limitam a comparação. Registrar método e fotos com escala. Não confundir comprimento curvo de um ligamento com corda da célula.

Importação CSV/JSON e formulário funcionam localmente. Cada observação exige experiment_id/sample_id, peça, design e célula válida. Medidas são quatro valores positivos ou quatro campos vazios. Uma ocorrência de falha pode existir sem medidas. Duplicatas e condições de processo conflitantes dentro da amostra são rejeitadas. Exportar antes de fechar: os dados não são persistidos nem enviados ao servidor.

Os mapas comparam 100(λ1−1) previsto/medido. Erro = medido − previsto, em pontos percentuais. Valores ausentes ficam cinza. Spearman usa postos médios para empates e só é apresentado com ≥3 pares não constantes. Top-K usa K = min(10, max(1, floor(n/3))) para evitar selecionar todas as observações; empates na fronteira têm participação fracionária. Hotspot precision/recall usa demanda prevista de ligamento >30% contra failure explícito. Sem denominador, mostra ausência, não zero.

## Processo, calibração e validação

O procedimento de 14 passos está no ZIP. Registrar material/lote, perfil de impressão, equipamento/potência/distância de aquecimento, temperatura superficial, tempos de formar/manter/resfriar e método de medição. O cartão térmico documenta condições reais; não acrescenta temperatura ao solver. Sensores opcionais usam time_s, displacement_mm, force_n, temperature_c; gráficos só aparecem com pares válidos.

A calibração offline exige ≥5 células medidas em uma amostra Original e ≥5 em uma Candidate distinta da mesma peça. Nove configurações limitadas exploram boundary_anchor (1/3), bending_weight (0,005/0,02) e interior_anchor (0,00025/0,001), além do default. A escala axial fica fixa porque a rigidez absoluta não é identificável neste experimento geométrico.

Minimiza-se o RMS de diferenças de postos normalizados na calibração. Só soluções convergidas e com correlação definida podem vencer. Candidate só é avaliada após congelar os parâmetros. O relatório separa ajuste e validação, registra hashes dos dados e solver, e mantém previsões base intactas no site. Não houve ajuste a medidas físicas nesta versão. Separação de datasets no software não substitui um protocolo realmente cego e réplicas independentes.

## Story Mode e próximo ensaio

As 12 cenas percorrem objeto, problema, ferramentas, reconstrução, formação, extensões principais, mecanismos, Original, resposta geométrica, delta, limites da simulação e ciclo físico. Usam os mesmos dados da bancada. Metadados de câmera e narração estão em `story/storyboard.json`; roteiro em `VIDEO_STORYBOARD.md`. `npm run capture-story` produz 12 frames de 1920 × 1080 em `docs/video_frames/`. São composições offline dos mesmos datasets, não capturas pixel a pixel do navegador.

Próximo passo físico: revisar camadas e imprimir A/B/C/D do Sub-Merged sob condições equivalentes, registrar o processo e medir o plano proposto. HAB-2 pode receber Original reparado versus Reserve Search 3 como ensaio adicional independente. Nenhuma impressão ou termoformação foi iniciada pelo aplicativo.

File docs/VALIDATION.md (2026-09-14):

# Verificação v0.6 — Physical Validation Loop

Revisão concluída em 14 de setembro de 2026, antes da publicação para avaliação do autor.

- `npm test`: 36 testes JavaScript e 12 Python passaram. Incluem reprodução anterior, geometria/STL, correspondência dos dados, ajuste afim sob rotação e extensões conhecidas, isolamento de A/B/C/D, IDs, template vazio, correlação/empates, rejeição de duplicatas e separação de amostras.
- `npm run build`: bundles da bancada e Story Mode gerados sem erros. Auditoria das dependências: zero vulnerabilidades na versão instalada.
- Os sete novos STL são sólidos fechados de um corpo nos checks de exportação. Núcleo A/C idêntico; B/D equivalente dentro da tolerância; contatos A/B e C/D preservados. Nenhum teste físico foi executado.
- Template real de 80 células importado no navegador: permanece sem medidas e sem correlação. Uma fixture matemática descartável, explicitamente identificada como software QA e fora da pasta pública, verificou importação JSON, erro zero, Spearman 1 e Top-2 100%. Isso verifica software, não previsão física. Entrada manual de ocorrência sem comprimentos também foi verificada.
- Exportação de trabalho de calibração funcionou; reusar a mesma amostra para ambos os papéis foi rejeitado. Nenhum ajuste com dados físicos está incluído. A calibração offline ainda precisará ser exercitada com medições reais e condições repetíveis.
- Downloads verificados: ZIP físico íntegro com 26 arquivos; ZIP combinado baixado contém os dois STL escolhidos independentemente, com bytes iguais aos arquivos do catálogo. Nenhuma fixture de QA está no conteúdo público.
- Story Mode 01–12 foi percorrido na revisão anterior à pausa. Após os ajustes finais, cenas 01, 06/capture, 09/borda e 12/sem dados foram revisitadas. A captura pelo navegador gerou PNG válido em 1920×1080; o script offline gerou os 12 frames nessa resolução, com revisão visual de quadros principais.
- Workbench foi revisado em desktop: ferramenta STL real, rede formada, etapas, λ1/λ2/J/risco, mecanismo por célula, navegação por teclado, diferença geométrica exata e zoom da borda C. Print apresenta A/B/C/D e suas diferenças.
- Layout a 390×844: Print, Deformation, Experiment e Calibration sem transbordamento horizontal da página. A matriz de impressão tem rolagem horizontal própria.

Os resultados negativos de B/C/D permanecem publicados como hipóteses experimentais. Convergência e STL válido não demonstram melhoria física. Não houve nova inspeção de camadas desses sete STL na interface do Cura. A inspeção e o ensaio físico continuam sendo etapas de bancada.

## Registro preservado: bancada v0.5

Atualização para validação pelo autor: 14 de setembro de 2026.

- Originais e ferramentas preservados em `legacy/`. Baselines v0.1/v0.2 reproduzidos, com diferenças inferiores a 0,02 ponto percentual (`generated/baseline_reproduction.json`).
- Treze designs calculados com o mesmo solver, incluindo Original; 26 conjuntos de resultados, cinco etapas reais de continuação e 24 STL candidatos novos.
- Testes verificam correspondência entre campos, métricas, geometria e arquivos; gates das duas peças; hashes dos downloads; sólidos fechados com um corpo; preservação do aro; largura dos caminhos; conteúdo dos ZIP. Uma ablação confirma que a largura afeta a solução.
- CuraEngine 5.9.0 processou Original e Reserve Search 3 nas duas peças, com 20 camadas e sem avisos registrados. Resultados e hashes estão em `generated/slicer_validation.json`. Isso não substitui inspeção visual das camadas nem validação física.
- A bancada v0.5 foi vista no navegador em desktop: geometrias STL e rede conformada carregaram. A inspeção visual completa dos controles e do layout móvel permanece pendente.
- A inspeção final dos STL Reserve Search 3 na interface do Cura foi interrompida. A versão atual foi publicada a pedido do autor para sua validação, antes dessa conclusão.

## Limites da recomendação

Reserve Search 3 passa nos critérios relativos das duas peças. No Sub-Merged, os ligamentos críticos caem apenas de 98 para 97 e o pico aumenta 0,78 ponto percentual: a margem é pequena. A recomendação é de teste físico, sem demonstração de robustez.

Não houve impressão física, calibração de polímero, análise térmica ou validação de ruptura. Os estados conformados mostram a rede equivalente do solver, não um novo sólido deformado. As cores de demanda usam o resultado final em todas as etapas.

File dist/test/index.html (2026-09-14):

LAMPFORM LABv0.9

← Escolher outra peçaTEST · PHYSICAL EXPERIMENT

A PEÇA

# Qual experimento vai imprimir?

# Largura ou altura ajudam a formar?

Quatro amostras para comparar sob as mesmas condições.

Download all 4 test parts ↓

Inclui os quatro testes e o molde correspondente. STLs existentes da v0.8 · camadas de 0,1 mm. Controle = referência uniforme gerada. Nenhuma medição física registrada ainda.

1. Imprima com o mesmo material e as mesmas configurações.
2. Aqueça sob a mesma condição e registre tempo e temperatura.
3. Forme com o molde correspondente à peça.
4. Compare onde as células abrem, torcem ou falham.
5. Retorne com medidas antes e depois do ensaio.

A altura muda rigidez e aquecimento. O modelo ainda não calibra o efeito térmico local.

Pesquisa aberta · previsões geométricas, sem validação física.Código e método ↗ (https://github.com/tbernard0-GTA/lampform-lab)

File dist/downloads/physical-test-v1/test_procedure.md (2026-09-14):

# EXPERIMENT V1 — MECHANISM SCREENING

Primeiro experimento: Sub-Merged, A/B/C/D. A é o original reparado, B acrescenta reserva apenas no interior, C modifica apenas dois conectores longos fora do núcleo e D combina exatamente B e C. Não há promessa de melhora física.

1. Imprimir A/B/C/D com o mesmo material, lote, orientação e perfil. Inspecionar todas as camadas no fatiador. Registrar as condições reais; não usar valores térmicos inventados.
2. Marcar as células selecionadas no mapa e identificar amostra e experimento. Fazer réplicas independentes quando possível; não confundir células com réplicas.
3. Fotografar a peça plana com escala e orientação de referência.
4. Posicionar no molde real, preservando a orientação.
5. Aquecer sob uma condição previamente definida para o material/equipamento. Registrar potência, distância e tempo.
6. Medir e registrar a temperatura superficial e o método de medição.
7. Executar o fechamento e registrar tempo/deslocamento.
8. Manter pelo tempo definido, registrando-o.
9. Resfriar sob condição repetível; registrar tempo.
10. Retirar a peça.
11. Fotografar com escala e referência de orientação.
12. Medir as células selecionadas. Definir dois segmentos materiais antes do teste, alinhados às direções de referência d1/d2 do mapa. Seguir os MESMOS pontos após formar; não reordenar L1/L2 pelo tamanho observado. Medidas são comprimentos de corda local, não percurso de um ligamento curvo. A curvatura e o ajuste afim geram erro de aproximação. Registrar fotos e método.
13. Registrar OK, stretched, opened, cracked, ruptured, wrinkled ou other; definir failure=true/false explicitamente e manter o mesmo critério entre amostras.
14. Importar CSV/JSON no LampForm. Comparar primeiro o ranking espacial. Não preencher células não medidas com zero.

## Calibration ≠ validation

Reservar amostras Original para calibração. Congelar parâmetros antes de abrir medidas Candidate de validação. Reportar por amostra; não combinar processos térmicos diferentes. Nenhum resultado físico foi registrado nesta versão.

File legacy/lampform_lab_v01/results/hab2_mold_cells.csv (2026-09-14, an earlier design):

cell | x0_mm | y0_mm | z_direct_mm | direct_edge_stretch_max | direct_edge_stretch_mean | x_relaxed_mm | y_relaxed_mm | z_relaxed_mm | relaxed_edge_stretch_max | relaxed_edge_stretch_mean | xy_shift_mm | boundary_cell | candidate_hex_side_mm | candidate_ligament_gap_mm | candidate_hole_scale
0 | -8.009178843548954 | -41.027240722156954 | 35.27880492488113 | 2.526685959227388 | 2.343784860758751 | -7.492513565321233 | -38.81018311158363 | 25.65118132279626 | 1.1934946162670603 | 1.1479838666886115 | 2.276463805626439 | True | 3.419086322299641 | 2.077968774313205 | 0.8547715805749102
1 | 8.009178843548954 | -41.027240722156954 | 35.27883119588289 | 2.5266881518480293 | 2.34378741431122 | 7.501749438383631 | -38.80945055185372 | 25.655086455367837 | 1.1915324466276336 | 1.148048111307399 | 2.2750995232560864 | True | 3.424977189981138 | 2.067765492188186 | 0.8562442974952845
2 | -20.0 | -34.10453414916992 | 29.67788419022853 | 2.0545197020758157 | 1.6155822559669044 | -18.771109548489704 | -32.626605399919335 | 24.258352220590833 | 1.1999654217447313 | 1.0969700498532573 | 1.9220939440294234 | True | 3.399659531620724 | 2.111616962797094 | 0.849914882905181
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

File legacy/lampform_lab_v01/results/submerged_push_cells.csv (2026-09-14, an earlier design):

cell | x0_mm | y0_mm | z_direct_mm | direct_edge_stretch_max | direct_edge_stretch_mean | x_relaxed_mm | y_relaxed_mm | z_relaxed_mm | relaxed_edge_stretch_max | relaxed_edge_stretch_mean | xy_shift_mm | boundary_cell | candidate_hex_side_mm | candidate_ligament_gap_mm | candidate_hole_scale
0 | -4.000001907348633 | -35.1775016784668 | 15.42552066295854 | 1.0427656044193165 | 1.0142554587700205 | -4.013450510481528 | -34.52232882934682 | 15.560594610402578 | 1.1475001090959895 | 1.0739464224892485 | 0.6553108629881057 | True | 3.5571720160012426 | 1.838797337023637 | 0.8892930040003106
1 | 3.999998092651367 | -35.1775016784668 | 15.425593207205218 | 1.0427630696692245 | 1.0142544854578317 | 3.9494109385517606 | -34.71903546855673 | 15.537263226109854 | 1.0884934922232472 | 1.0529790013963023 | 0.46124865939013443 | True | 3.7343229439055663 | 1.5319629292853767 | 0.9335807359763916
2 | -8.000001907348633 | -28.249298095703125 | 15.435460320821734 | 1.1703702124992759 | 1.0540048530332293 | -7.191360331417465 | -26.0032252595444 | 16.824788421622184 | 1.1475001090959895 | 1.0588366821751922 | 2.387204302872827 | False | 3.5571720160012426 | 1.838797337023637 | 0.8892930040003106
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

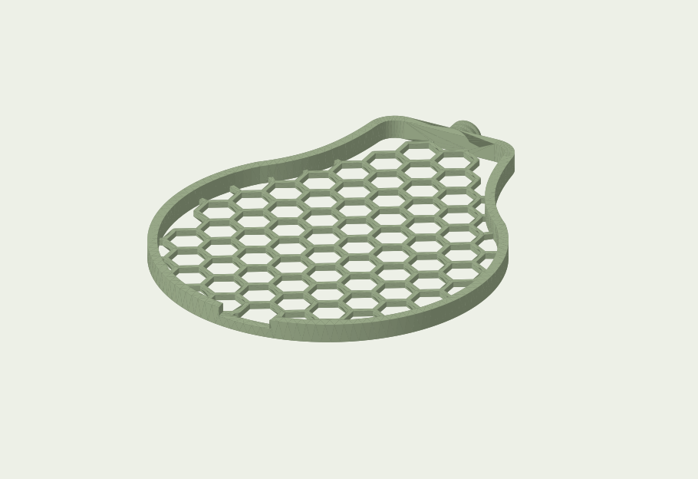
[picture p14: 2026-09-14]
dist/media/tests/peca-1-uniform_w10_h12.png

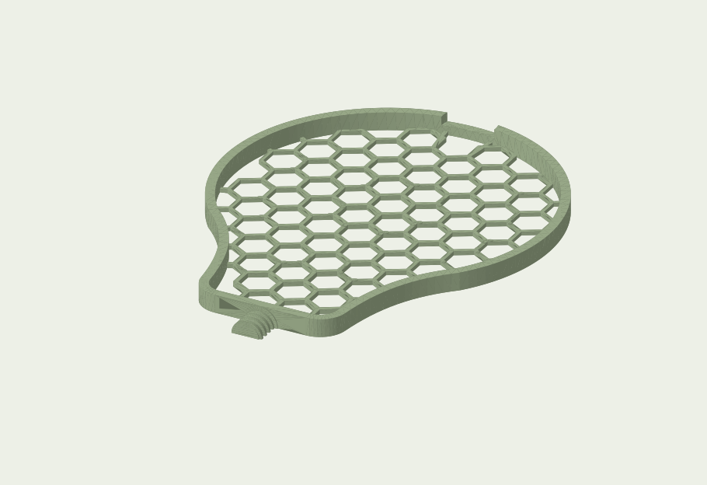
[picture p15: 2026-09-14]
dist/media/tests/peca-2-comply.png

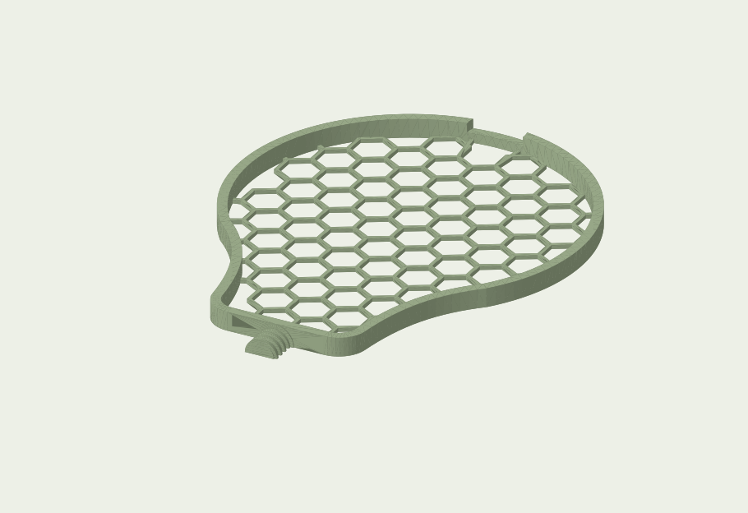
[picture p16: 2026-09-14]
dist/media/tests/peca-2-uniform_w8_h8.png

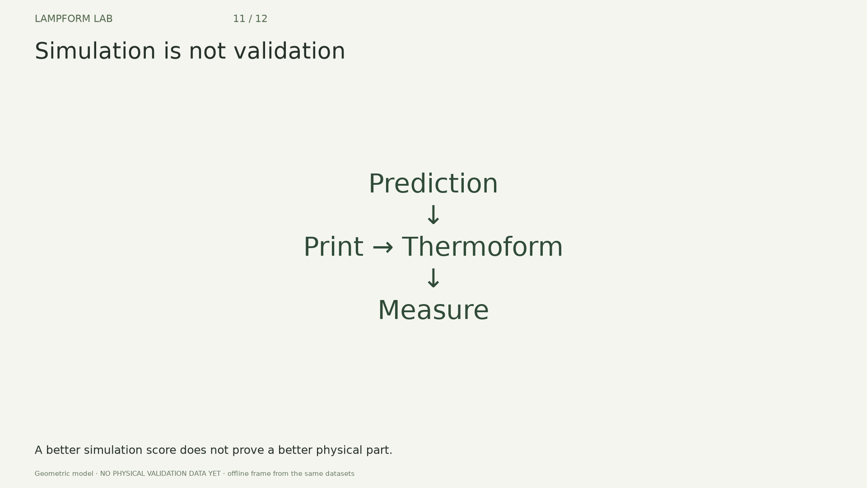
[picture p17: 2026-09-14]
docs/video_frames/11_validation.png

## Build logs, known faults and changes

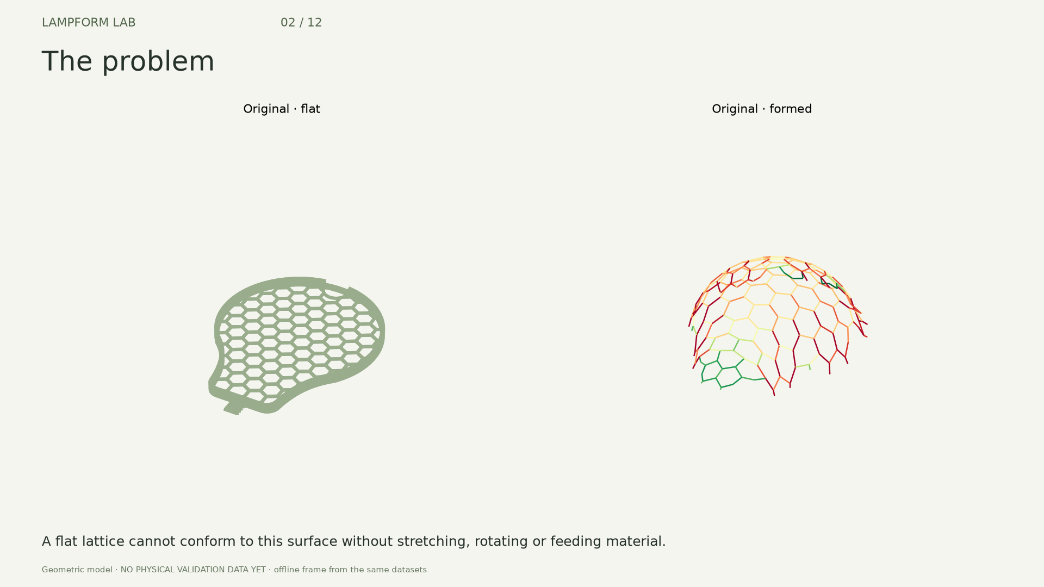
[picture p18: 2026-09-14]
docs/video_frames/02_problem.png

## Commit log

2026-09-14 Create public LampForm Lab research showcase with original models
    [hab2_mold_boundary_sensitivity.csv, hab2_mold_cells.csv, hab2_mold_ligaments.csv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]
2026-09-14 Build engineering workbench and gated offline design space (visual QA pending)
    [HAB-2.stl, HAB-2_TEST_V1.stl, HAB-2_TEST_V1_reserve_search_3.stl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]
2026-09-14 Publish workbench for author validation with explicit print-test limits
2026-09-14 Add v0.6 physical validation loop and documentary story mode
    [HAB-2.stl, HAB2_original_repaired_for_test.stl, ORIGINAL_HAB2.stl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]
2026-09-14 Add v0.8 parametric lattice lab and seven-chapter research story
    [A_uniform.stl, B_width.stl, C_height.stl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]
2026-09-14 Simplify exploration and test flows; name deliverables Piece 1 and Piece 2
    [molde-peca-1.stl, molde-peca-2.stl, peca-1-altura.stl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]
